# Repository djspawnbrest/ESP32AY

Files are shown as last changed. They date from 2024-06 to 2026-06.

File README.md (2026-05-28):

# ZxPod - multiformat Turbo Sound player
ESP32 based AY Turbo Sound multiformat player

## Fast flash firmware avaliable on [Alex Spawn OTA web page](https://ota.alexspawn.ru)

## Starting with firmware version 3.41 - added support for external DAC's - read [External DAC](PCB/ExternalDAC)

## IMPORTANT:
Firmwares from version 3.4 supports only PCB revision C! But you can soldering upgrade revision A and B to C:

Cut JP1 jumper on revisions A and B first!

### From rev.A to B and C:
You need to cut the input track on the resistor R33(see Pic.2) and solder the wire from the ESP32 (see Pic.1) to the cut contact of the resistor. See the images below.
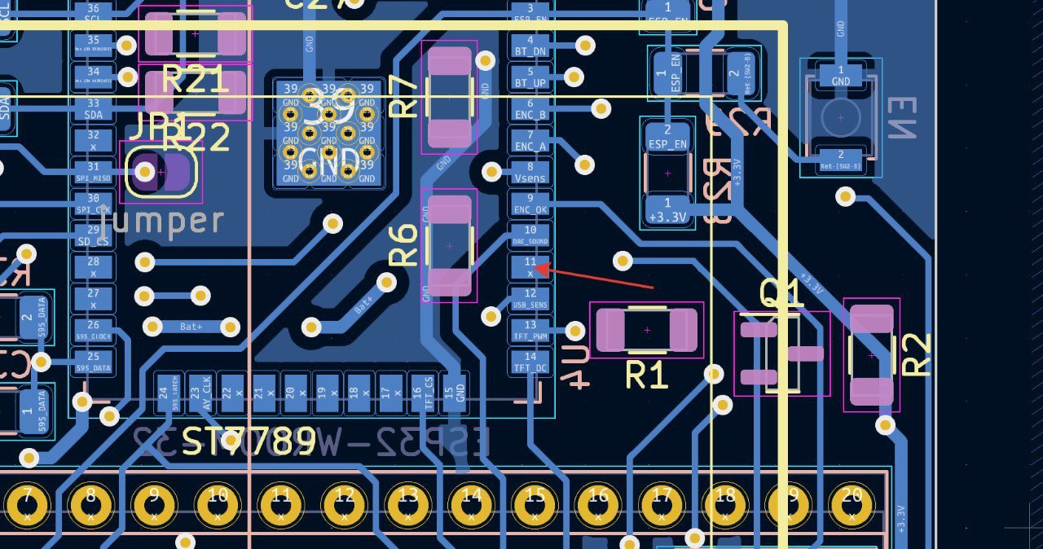
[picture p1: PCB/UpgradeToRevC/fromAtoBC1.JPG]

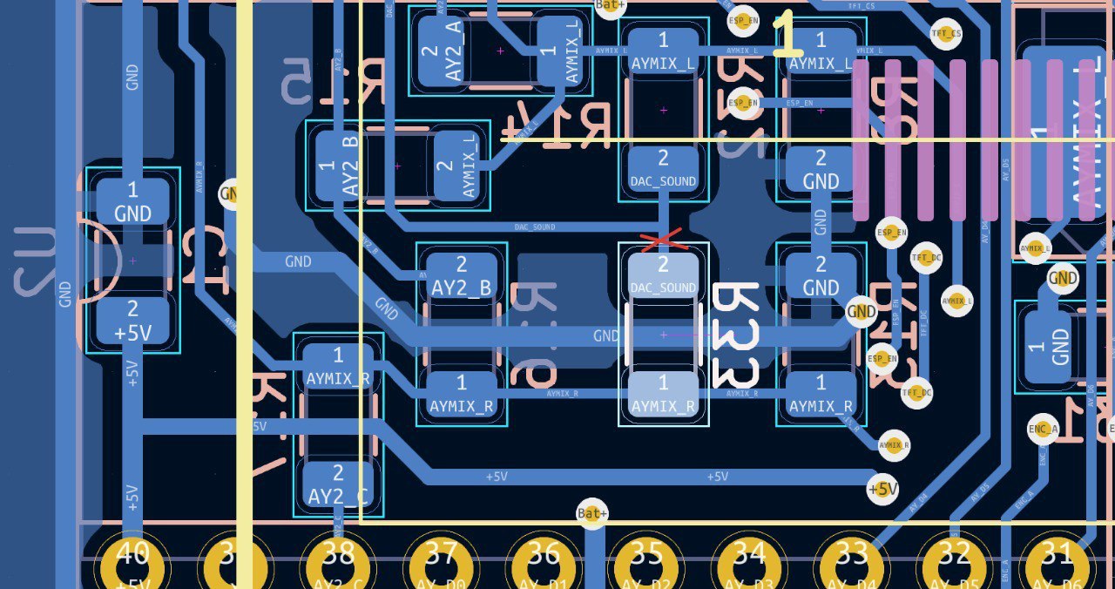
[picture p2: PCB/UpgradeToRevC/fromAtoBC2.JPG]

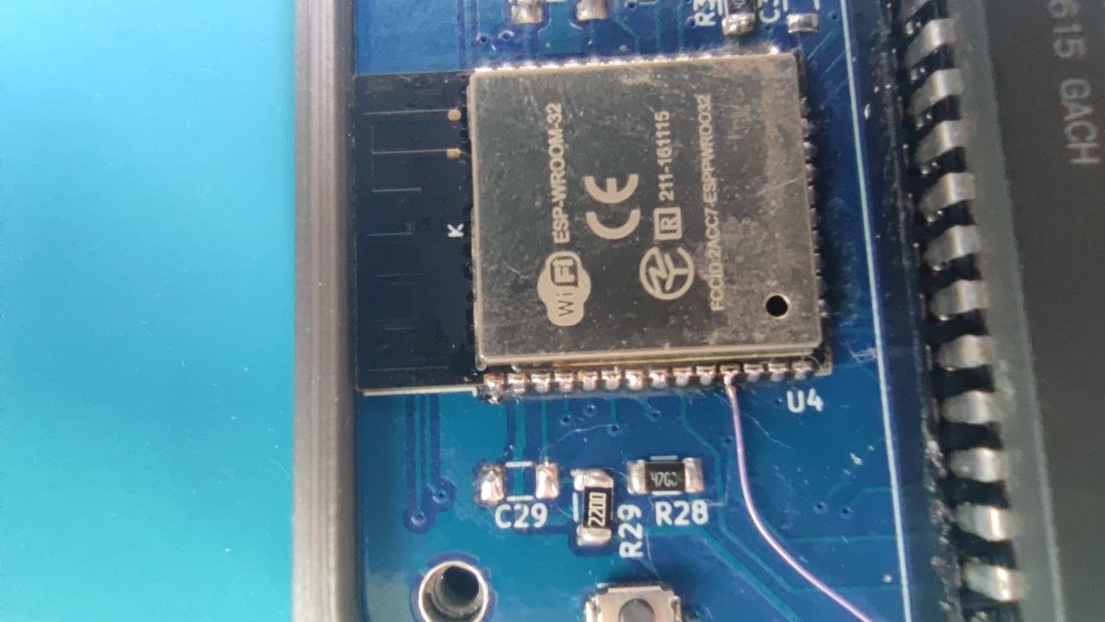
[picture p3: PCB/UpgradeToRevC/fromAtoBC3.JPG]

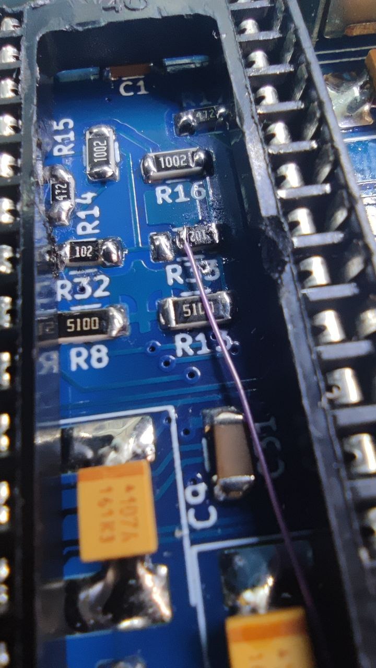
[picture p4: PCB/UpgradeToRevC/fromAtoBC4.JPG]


### From rev. A and B to C:
You need to cut the tracks as shown in Figure 5 (red cut lines), then carefully strip the tracks from the solder mask and solder the wires (green lines) to the ESP32.
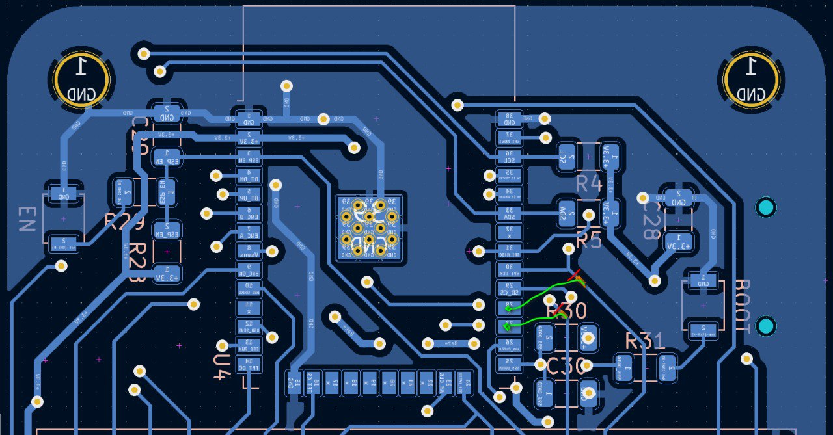
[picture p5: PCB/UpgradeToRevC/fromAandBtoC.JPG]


## Features
### Supported formats:
- .ayl - [Ay_Emul](https://bulba.untergrund.net/emulator_e.htm) by Sergey Bulba own playlist format
- .pt1 - Pro Tracker v1 file format
- .pt2 - Pro Tracker v2 file format
- .pt3 - Pro Tracker v3 (include Turbo Sound on two AY chips) file format
- .stc - Sound Tracker file format
- .stp - Sound Tracker Pro file format
- .asc - Sound Master file format 
- .psc - Pro Sound Creator file format
- .sqt - SQ Tracker file format
- .ay  - AY file format
- .psg - Programmable Sound Generator file format
- .rsf - Registers Stream Flow file format
- .yrg - [Custom AVR-AY format](https://www.avray.ru/ru/avr-ay-player/)
- .mod - Amiga MOD tracker format designed for creating, storing and playing music on an Amiga PC
- .s3m - (Scream Tracker 3 Module) is a module file format, based on the original MOD format used on the Amiga computer.
- .xm  - The XM file format, also known as Extended Module, is a digital audio file type for music created in the FastTracker 2 software (rev.D and above only).
- .tap - A file format for emulating ZX Spectrum magnetic tape images, which stores data from standard Sinclair BASIC procedures for working with a cassette.
- .tzx - A file format used to store programs and games for the ZX Spectrum computer as audio data from magnetic tape.
- .mp3 - MP3 (MPEG-1 Audio Layer 3) is a widely used digital audio format that uses a lossy compression method to significantly reduce file size while maintaining near-CD quality audio.
- .wav - is an audio file format for storing uncompressed audio data, developed by Microsoft and IBM. It is known for high-quality audio that retains all original data, but results in large file sizes, making it popular for professional audio recording and editing. The format stores audio data in chunks and commonly uses linear pulse-code modulation (LPCM) for encoding.
- UART mode (available in player settings menu as Player source)
- SD forwarding via USB as Mass Storage device (rev.D and above only) (press left button("-") and turn ON player)

### Controls
- Before player turning on - hold left button and turn on player to enter root config (needed for change encoder type). Encoder types:
    1. STEP 4L - active low (pull-up to VCC). Full cycle (4 phases) per click.
    2. STEP 4H - active high (pull-up to GND). Full cycle (4 phases) per click
    3. STEP 2 - half cycle (2 phases) per click (Set by default)
    4. STEP 1 - quarter cycle (1 phase) per click, and non-latching encoders
- Before player turning on - hold right button and turn on player to reset config to default.
- Before player turning on - hold encoder button and turn on player to reset last playing track (if player freezes or reboot on this file).
- Encoder Hold - change mode player/file browser
- Encoder Click - in player mode - play/pause; in file browser mode select track/playlist/directory; select - in config mode
- Encoder Double click - in player mode - open settings
- Encoder Push and turn right - fast forward (for ay format change next subsong, for tape formats - change next block)
- Encoder Push and turn left - slow down (for ay format change previous subsong, for tape formats - change previous block)
- Left button click/hold - volume - (in player mode); cancel - in config mode
- Right button click/hold - volume + (in player mode)
- Left button double click - change AY clock (in player mode) for PSG formats or change stereo panning for formats over DAC (mod,s3m etc.)
- Right button double click - change play mode: all/shuffle/once (in player mode)
- Right button hold and encoder click - remove file (only files, only in file browser).
- Right button click - change file sorting in file browser. (only in file browser).

### Playing modes:
- Playing all tracks (in folder/playlist)
- Playing random track (in folder/playlist)
- Playing once track (loop)

### Supports fully realtime file browser

### Supports realtime AY layers change:
- ABC
- ACB
- BAC
- BCA
- CAB
- CBA

### Supports realtime AY clock change:
- ZX SPECTRUM - 1773400 Hz
- PENTAGON - 1750000 Hz
- MSX - 1789772 Hz
- CPC - 1000000 Hz
- ATARI ST - 2000000 Hz

### Built-in battery

### Built-in charger and indication on LED and TFT

### Built-in headphones stereo amplifier controlled by I2C bus

## Demo video with digital sound record:

Watch the video (https://youtu.be/-dr-m1xszBs)

### UPD 22.10.2024
- Add new feature: "UART mode" with AVR-AY player through UART.

### UPD 04.03.2025
- Add new formats: .mod and .s3m tracker module formats
- Change PCB to revision C

### UPD 18.06.2025
- Change PCB to revision D (ESP32 chip change to ESP32-S3 (N16R8) chip)

### UPD 16.07.2025
- SD forwarding via USB as Mass Storage device (rev.D and above only)

### UPD 12.09.2025
- Add .xm file format (rev.D and above only). Change Firmware version to 3.5

### UPD 15.10.2025
- Add .tap, .tzx formats to play and loads programms on ZX-Spectrum.

### UPD 08.10.2025
- Add .mp3, .wav formats.

### UPD 10.10.2025
- Add file sorting in file broser on right button click!

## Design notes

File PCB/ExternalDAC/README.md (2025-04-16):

# ZxPod Player withexternal DAC use
## Revisions A,B and C.

You may use external DAC like PCM5102A module.

### First prepare PCM5102A module

1. Solder SCK jumper on top side.
2. Solder jumpers on bottom side: 1 - LOW, 2 - LOW, 3 - HIGH, 4 - LOW

### Prepare ZxPod
1. Remove R18, R19, R32, R33 (on revisions A,B and C).
2. Connect BCK DAC pin to GPIO25, DIN DAC pin to GPIO26, LRCK DAC pin to GPIO27 (see Fig.1)
3. Connect VIN DAC pin to 5V on player and GND DAC pin to GND on player (You may use 3,3V linear regulator pins on player PCB, see Fig.2)
4. Connect LROUT DAC pin to LOUT pad R32 (see Fig.2), ROUT DAC pin ROUT pad R33 (see Fig.2)
5. Fix the module, for example, with double-sided tape to the ESP32 module as shown in Fig.3

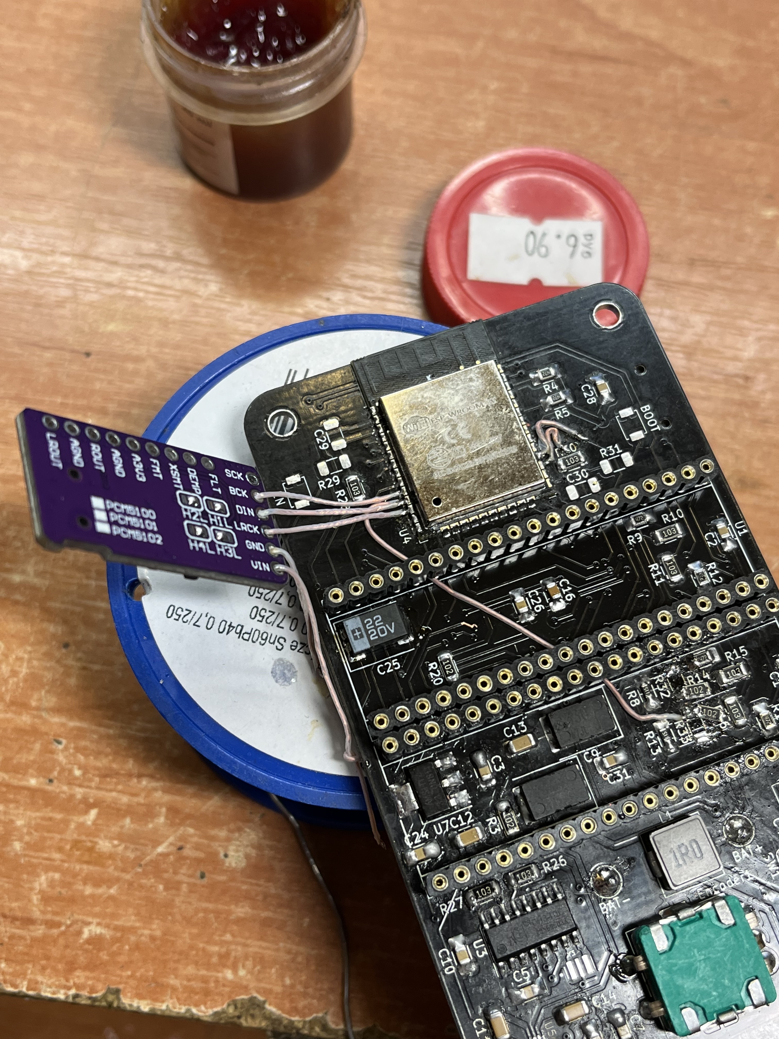
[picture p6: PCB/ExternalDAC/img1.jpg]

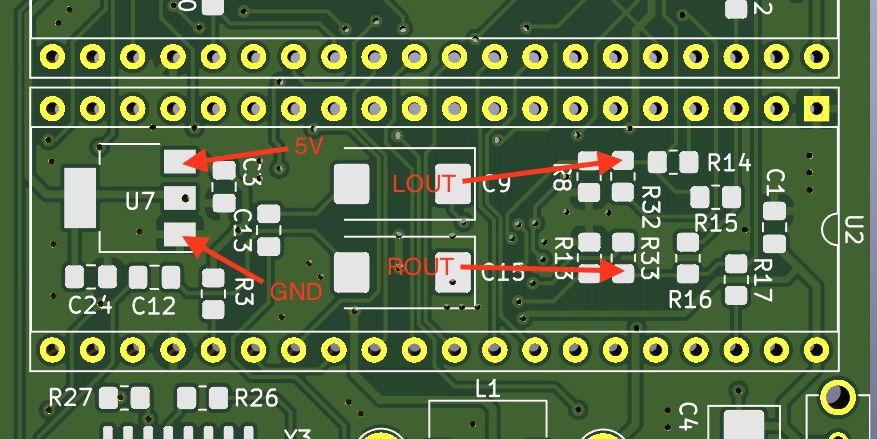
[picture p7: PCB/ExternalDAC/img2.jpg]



External DAC support starting from firmware version 3.41.
Also fast firmware flash avaliable on [Alex Spawn OTA web page](https://ota.alexspawn.ru)

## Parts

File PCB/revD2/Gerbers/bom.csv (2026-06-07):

Designator | Footprint | Quantity | Value | LCSC Part #
C1 | CP_EIA-7343-31_Kemet-D-uni | 1 | 100uf
C10, C24, C27, C37, C38, C39, C40, C41, C42, C9 | 0805 | 10 | 10uf
C11, C14, C17 | 1206 | 3 | 22uf
C12, C13, C15, C16, C18, C19, C2, C20, C21, C22, C25, C29, C3, C34, C35, C36, C4, C5, C6, C7 | 0805 | 20 | 100n
C23, C43, C44 | 0805 | 3 | 2.2uf
C26, C28 | 0805 | 2 | 2.2nf
C30, C31, C32, C33 | 0805 | 4 | 470n
C8 | CP_EIA-7343-31_Kemet-D-uni | 1 | 47uf
D1 | 0805 | 1 | OK
D2 | 0805 | 1 | CHRG
D3 | D_SOD-323F | 1 | PMEG4010CEJ
D4 | D_SMA | 1 | SS14
D5 | 0805 | 1 | PWR
ENCODER1 | RotaryEncoder_Alps_EC11E-Switch_Vertical_H20mm | 1 | RotaryEncoder_Switch
J1 | USB_C_Receptacle_G-Switch_GT-USB-7010ASV | 1 | USB_C_Receptacle_USB2.0_14P
J2 | JST_PH_S2B-PH-K_1x02_P2.00mm_Horizontal | 1 | Battery
J3 | TFP09212B | 1 | SD Card
J4 | AUDIO_JACK_3.5MM_SMD_TRRS_rounded_mixed | 1 | MiniJack
L1 | L_Bourns_SRN8040TA | 1 | 22uH
Q1 | SOT-23 | 1 | IRLML6402
Q2 | SOT-23 | 1 | BC807
R1, R11, R13, R18, R2, R25, R26, R32, R39, R40, R41, R42, R6, R7, R8, R9 | 0805 | 16 | 10K
R10, R22, R23, R24, R29, R45, R46, R47, R48, R49, R50 | 0805 | 11 | 1k
R12 | 0805 | 1 | 8,2К*
R14 | 0805 | 1 | 1M
R15 | 0805 | 1 | 100K
R16 | 0805 | 1 | 2k*
R17, R19 | 0805 | 2 | 220
R20 | 0805 | 1 | 47k
R21 | 0805 | 1 | 6.2k
R27, R28, R30, R31 | 0805 | 4 | 470
R3, R4 | 0805 | 2 | 5K1
R33, R34, R35, R36, R37, R38 | 0805 | 6 | 4.7K
R43, R44 | 0805 | 2 | 1.5K
R5 | 0805 | 1 | 2R
R51, R52 | 0805 | 2 | 15K
S1 | SW_Push_1P1T_NO_6x6mm_H9.5mm | 1 | DOWN
S2 | SW_Push_1P1T_NO_6x6mm_H9.5mm | 1 | UP
S3 | SW_EG1213 | 1 | EG1213
SW1 | SW_SPST_PTS810_handsoldering | 1 | BOOT
SW2 | SW_SPST_PTS810_handsoldering | 1 | EN
TFT1 | ST7789 | 1 | ST7789
U1 | SOT-223-3_TabPin2 | 1 | AMS1117-3.3
U10 | TSSOP-20_4.4x6.5mm_P0.65mm | 1 | PCM5102A
U11 | ESP32-S3-WROOM-1 | 1 | ESP32-S3-WROOM-1
U12 | QFN50P400X400X80-21N | 1 | TPA6130A2RTJTG4 | TPA6130A2RTJTG4
U2, U3 | SO-16_3.9x9.9mm_P1.27mm | 2 | 74HC595
U4 | SOIC-8-1EP_3.9x4.9mm_P1.27mm_EP2.41x3.3mm_ThermalVias | 1 | TP4056
U5, U7 | DIP-40_W15.24mm_Socket | 2 | AY-3-8910
U6 | SOIC-8_3.9x4.9mm_P1.27mm | 1 | DS3231MZ
U8 | SOT-23-6_Handsoldering | 1 | SDB628
U9 | SOIC-8_3.9x4.9mm_P1.27mm | 1 | 24С32

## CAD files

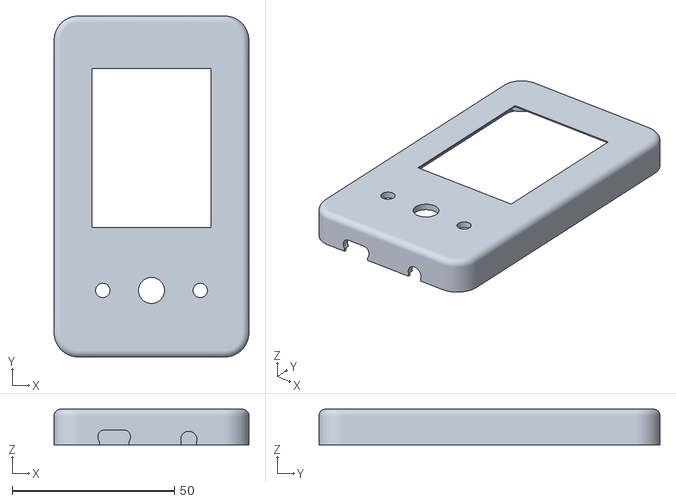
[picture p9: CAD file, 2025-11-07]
Case/TopRevABCD.stl
60.0 x 105.0 x 11.0

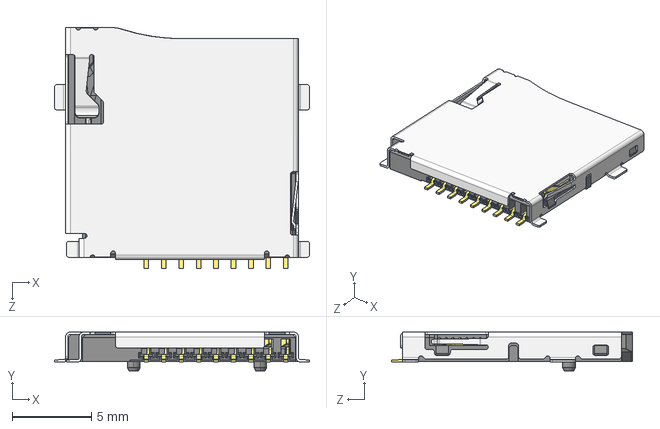
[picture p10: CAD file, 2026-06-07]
PCB/revD2/KiCad/3d/TFP09-2-12B.stp
16.1 x 2.45 x 15.2 mm

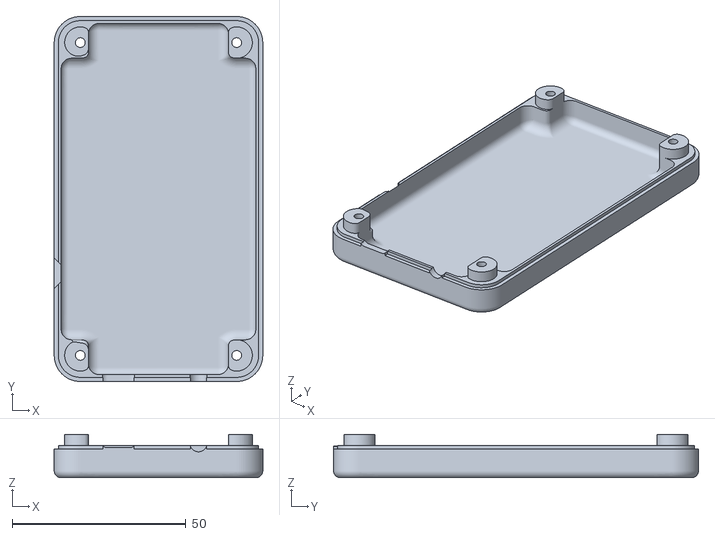
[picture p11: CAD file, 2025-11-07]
Case/BottomRevABCD.stl
60.0 x 105.0 x 12.5

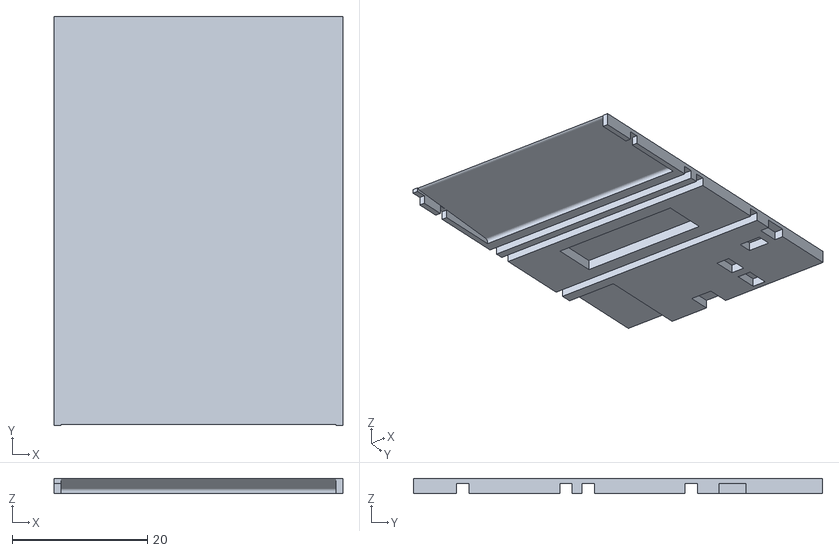
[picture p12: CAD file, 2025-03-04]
Case/LCDspacerRevABCD.stl
42.7 x 60.4 x 2.21

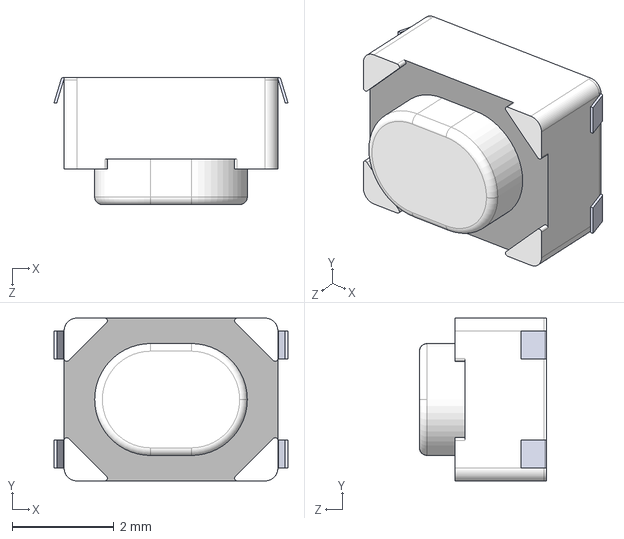
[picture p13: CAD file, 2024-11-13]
PCB/revD2/KiCad/3d/PTS810 Series SJS 250.STEP
4.60 x 3.20 x 2.50 mm

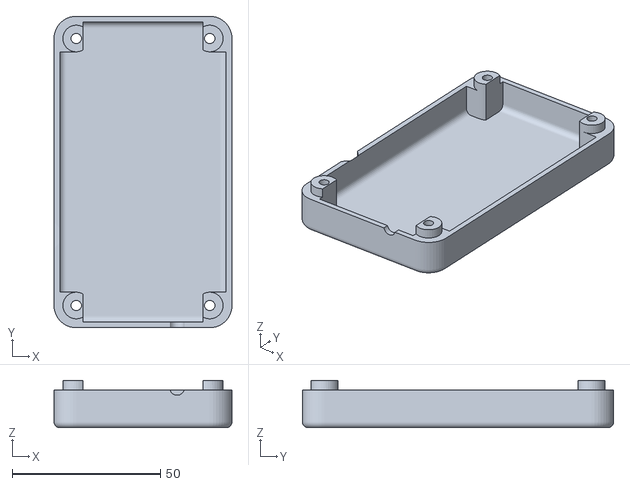
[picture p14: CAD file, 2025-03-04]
Case/ExtendedBottomMicroUsbRevA.stl
60.0 x 105.0 x 16.0

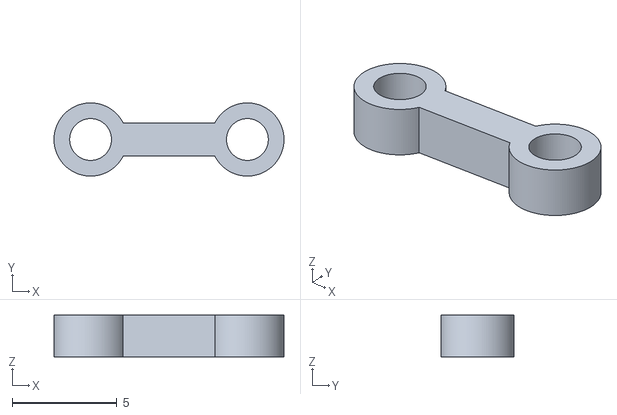
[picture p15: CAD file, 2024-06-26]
PCB/revD2/KiCad/3d/heliPerem.stl
11.0 x 3.50 x 2.00

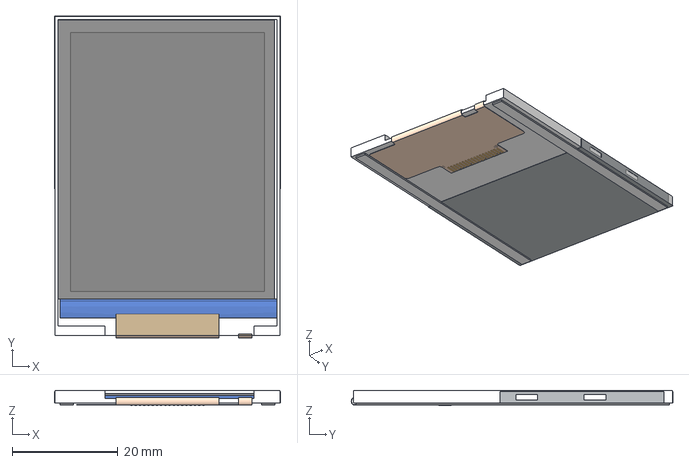
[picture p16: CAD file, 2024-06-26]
PCB/revD2/KiCad/3d/2.4 TFT Module.step
42.7 x 60.8 x 2.74 mm

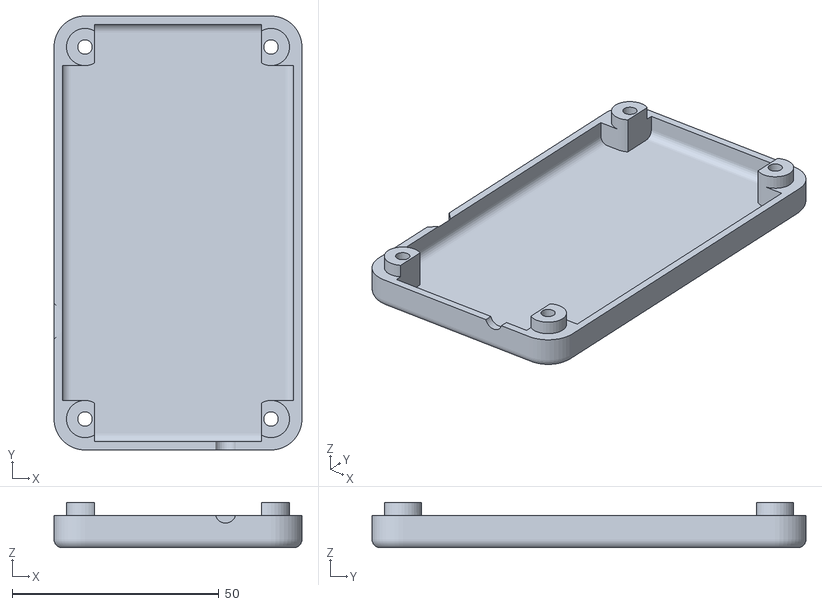
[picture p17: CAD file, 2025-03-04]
Case/BottomMicroUsbRevA.stl
60.0 x 105.0 x 11.0

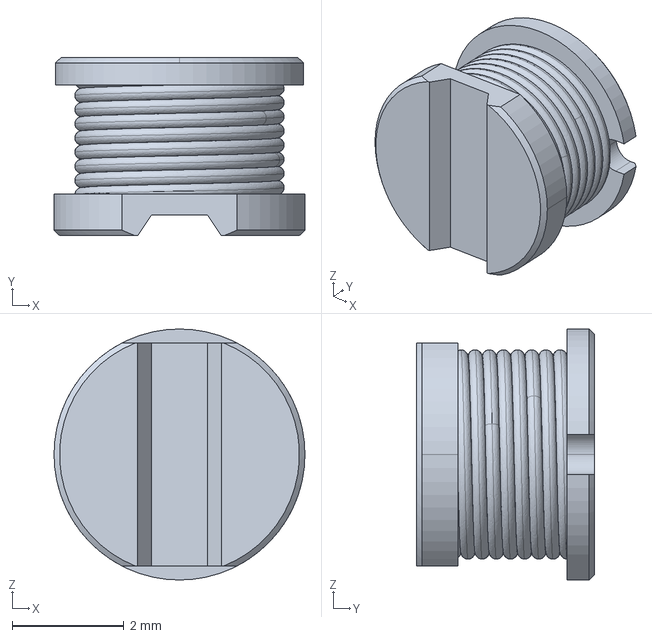
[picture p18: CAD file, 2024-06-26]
PCB/revD2/KiCad/3d/SDR0403-221KL.step
4.50 x 3.20 x 4.50 mm

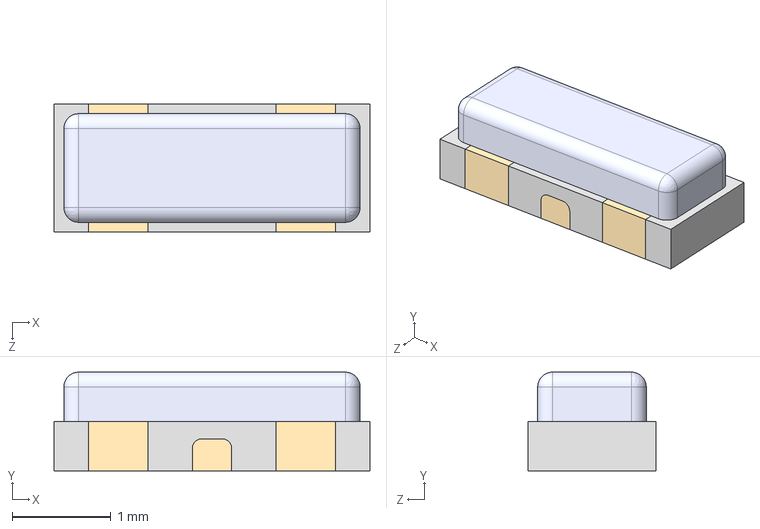
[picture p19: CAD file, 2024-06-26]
PCB/revD2/KiCad/3d/CSTCE16M0V53-R0.step
3.20 x 1.00 x 1.30 mm

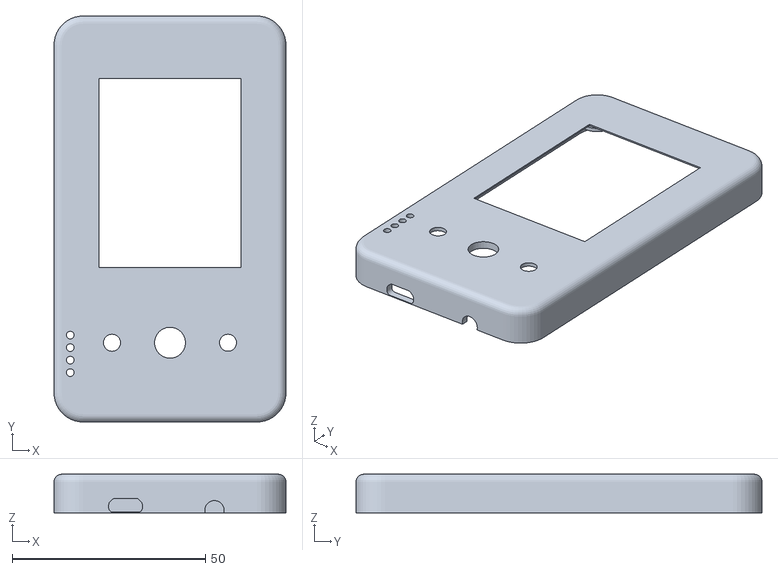
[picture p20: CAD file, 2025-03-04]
Case/TopMicroUsbRevA.stl
60.0 x 105.0 x 10.00

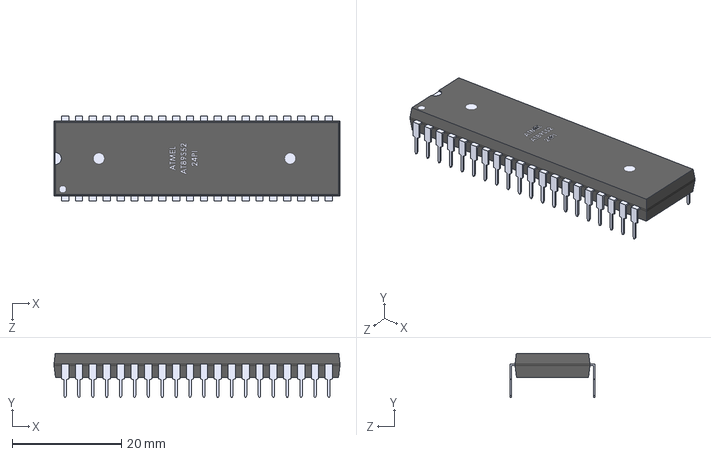
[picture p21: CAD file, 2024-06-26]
PCB/revD2/KiCad/3d/AYDIP40_MODEL.STEP
52.3 x 8.13 x 15.6 mm
AT89S52_PIN21to40 x 40
AT89S52_body

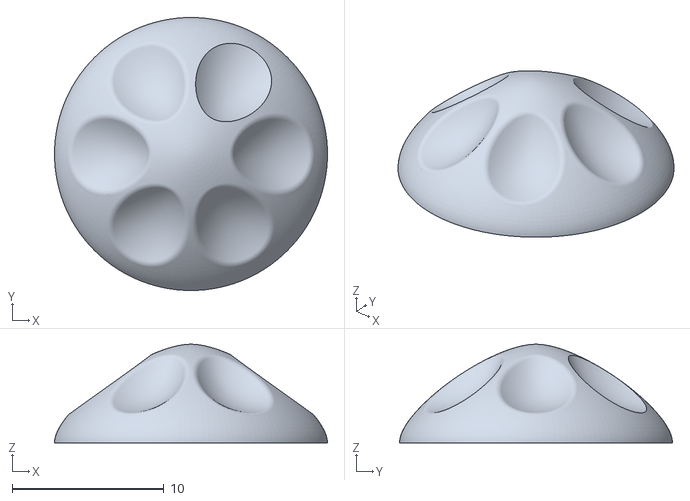
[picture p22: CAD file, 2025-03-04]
Case/EncoderKnob.stl
18.0 x 18.0 x 6.50

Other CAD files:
Case/ExtendedBottomTypeCRevBC.stl
Case/BottomTypeCRevBC.stl
PCB/revD2/KiCad/3d/ZX62D-B-5P8.step
Case/OldCases/BottomTypeCRevBC.stl
Case/OldCases/ExtendedBottomTypeCRevBC.stl
Case/OldCases/TopTypeCRevBC.stl
Case/TopTypeCRevBC.stl
PCB/revD2/KiCad/3d/35RAPC2BHN2.step
PCB/revD2/KiCad/3d/ArduinoMega_STEP_AP203.STEP
PCB/revD2/KiCad/3d/EC11-THT-15F.step
PCB/revD2/KiCad/3d/EC11-THT-15_rotated.step
PCB/revD2/KiCad/3d/EG1213.step
PCB/revD2/KiCad/3d/FSM8J.STEP
PCB/revD2/KiCad/3d/GMT177-01.iges
PCB/revD2/KiCad/3d/ME2108A33P.step
PCB/revD2/KiCad/3d/SS14.step
PCB/revD2/KiCad/3d/SSD1306_OLED_Display(128x64).step
PCB/revD2/KiCad/3d/TP4056.step
PCB/revD2/KiCad/3d/TPA6130A2RTJTG4.step
PCB/revD2/KiCad/3d/Tactal Switch -Thru (6mmx 6mmx9.0mm).stp
PCB/revD2/KiCad/3d/audio_3.5mm_trrs.STEP
PCB/revD2/KiCad/3d/tft1.8.step

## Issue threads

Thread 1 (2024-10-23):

Another display

kpbicka, 2024-10-23:
Добрый день. Возможно ли пересобрать под использование дисплеев на контроллере ILI9341 ?

djspawnbrest, 2024-10-24:
Да, библиотека поддерживает этот контроллер

kpbicka, 2024-10-24:
> > Добрый день. Возможно ли пересобрать под использование дисплеев на контроллере ILI9341 ?
>
> Да, библиотека поддерживает этот контроллер, надо только в библиотеке его выбрать и прописать настройки. Соответственно пины проверить на совместимость.

А ещё расскажите, пожалуйста, как оно работает по UART (ну или где это описано - не нашёл)

kpbicka, 2024-10-24:
И в веб-прошивальщике неплохо бы сделать выбор скорости, а то не всегда получается на той, что по умолчанию (которая не отображается) :)

djspawnbrest, 2024-10-24:
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

Заходим в настройки (двойной клик энкодера из плеера), там верхний пункт меню "Player Source" - переключает источник проигрывания SD/UART. Качаем плеер AVR-AY Player, устанвливаем, запускаем его, снимаем галочку "USE SOUND CARD", выбираем ком порт подключенного плеера - Open. Запускаем треки из плейлиста плеера.....

djspawnbrest, 2024-10-24:
> И в веб-прошивальщике неплохо бы сделать выбор скорости, а то не всегда получается на той, что по умолчанию (которая не отображается) :)

Такой реализации у разработчика пока нет.

djspawnbrest, 2024-10-24:
> >
>
> а почему у вас в User_Setup.h #define ILI9341_DRIVER но используется вроде ST7789 ?

Потому что это всего лишь название файла с его id, а если посмотреть его внутри то там вообще прописан [#define ST7789_DRIVER](https://github.com/djspawnbrest/ESP32AY/blob/main/lib/TFT_eSPI/User_Setups/Setup42_ILI9341_ESP32.h#L7). Просто по набору настроек больше подходил мне, вот его я и переписал.

mszulen, 2024-12-18:
And what, exactly display did you use? Any chance for a link to the seller?

djspawnbrest, 2024-12-18:
> And what, exactly display did you use? Any chance for a link to the seller?

For example use this: https://aliexpress.ru/item/1005005824438283.html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
or
https://aliexpress.ru/item/1005005287329824.html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

It doesn't matter with touch or without, it is not used.

mszulen, 2024-12-18:
Perfect! Thank you! :)

Closed 2025-02-10.

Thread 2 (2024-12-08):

ESP32 version

mszulen, 2024-12-08:
Does it matter which version of ESP32 WROOM 32 is used? I mean 32, 32D, 32E ?

djspawnbrest, 2024-12-08:
I used 32 version

mszulen, 2024-12-09:
Thanks! According to specs, the "D" version doesn't seem to be different on the functional level. Do you think it will also work? This is what I have.

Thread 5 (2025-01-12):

Initial run issues (was: Blinking led and no boot)

mszulen, 2025-01-12:
Firmware has been flashed suscesfully, but it does not boot.
Does it require the battery too or it can run on usb only?
I'm getting the "25%" led blinking and the LCD just blinks once (or sometimes not) after I turn it on.
Any suggested areas to check?

djspawnbrest, 2025-01-12:
It is better to connect the battery, the charging controller does not work without it.

mszulen, 2025-01-12:
Thanks!
Ok, I've had to:
1. flash the combined firmware (separate components did not work for some reason)
2. add the battery

It did boot (I can add AY chips and buttons now).

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

However, there's a weird behaviour:

Looks like It turns on ONLY every second flip of the switch.

This is the sequence I observe

1. flip switch to ON - nothing happens (no LEDs, no LCD)
2. flip to OFF
3. flip to ON again - LEDs come on and it boots
4. flip to OFF
5. go to step 1

Is this somehow to avoid?

mszulen, 2025-01-12:
And one step further.
With and without encoder, it behaves like the encoder was pushed/turned all the time (see the video).
I've tried beta and merged firmware - no change.

pins 6, 7, 9 of ESP are on ab. 3.2V
Rotating or shorting of the encoder pins does drop the voltage on those pins, so looks like resistors and capacitors there are ok.

https://drive.google.com/file/d/1z1_PquUsFGeYMXxUE6-IOWNntH5dRp3-/view?usp=sharing

djspawnbrest, 2025-01-12:
ym format is not supported, see readme) you need to write on your sd card only supported formats.

djspawnbrest, 2025-01-12:
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

See your connections on PCB

andykarpov, 2025-01-12:
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

I can confirm exactly the same issue like on the video with that play/pause loop for every 0.5-1 seconds after flashing the firmware and first run. Then somehow after some clicks on the encoder button to enter the setup menu, choosing the UART mode - it was gone. I think this is a software bug somewhere that needs to be investigated and fixed.

mszulen, 2025-01-12:
> ym format is not supported, see readme) you need to write on your sd card only supported formats.

Right. I've selected correct files later but behaviour was the same.
Somehow, After trying to click, rotate encoder, I've got to the file list and the encoder was working correctly. I could select/play the files (but not skip to next/previous track with hold/turn). I've replicated the issue by selecting "reset to default" in the setting menu.
The encoder stopped working again.
Is there some parameter that causes this?

Btw, wouldn't it work if the track skipping was done by just rotation of the encoder. Seem like most of the times mine doesn't register press and turn and just goes to the file list like with long-press.

mszulen, 2025-01-12:
> I can confirm exactly the same issue like on the video with that play/pause loop for every 0.5-1 seconds after flashing the firmware and first run. Then somehow after some clicks on the encoder button to enter the setup menu, choosing the UART mode - it was gone. I think this is a software bug somewhere that needs to be investigated and fixed.

exactly same thing in my case. But it was gone again after reset to defaults.

andykarpov, 2025-01-12:
I think it could be related to the LittleFS storage uses on flash to store config files.
Maybe LittleFS requires a forced format before usage on first start?
You can provide a first argument to ```true``` while calling the ```LittleFS.begin()```

andykarpov, 2025-01-12:
Well, another finding is the F_CPU/256 is not equal to 312500. The current F_CPU is 160000000, so to get 312500 we have to divide F_CPU by 512... After changing that parameter to F_CPU/512 a strange noise from DAC has gone! And the initial boot also seems works fine.

mszulen, 2025-01-12:
It's amazing, how one finding leads to another :)
Thank you, guys for working on this.
What about the track skip? Is it viable/possible to skip tracks by turning the encoder only instead of press-turn?

djspawnbrest, 2025-01-12:
> It's amazing, how one finding leads to another :) Thank you, guys for working on this. What about the track skip? Is it viable/possible to skip tracks by turning the encoder only instead of press-turn?

it is intended that simply turning switches the next/previous track, but pressing and turning speeds up and slows down the track (in player mode, not file browser).

andykarpov, 2025-01-12:
> > Well, another finding is the F_CPU/256 is not equal to 312500. The current F_CPU is 160000000, so to get 312500 we have to divide F_CPU by 512... After changing that parameter to F_CPU/512 a strange noise from DAC has gone! And the initial boot also seems works fine.
>
> Thank you for feedback, I forgot about this when changed CPU speed, I fix this moment soon.

Well, my finding with the F_CPU fixes the DAC noise problem, but it's seems "reset to defaults" still produces that strange loop in player mode with bad encoder/buttons reaction. But definitely it's related to the DAC somehow, I guess.

andykarpov, 2025-01-12:
Steps to reproduce a case with stuck on play loop:
1. SD card should contain only one directory "music" with some pt3 files in it
2. No other files or directories on the SD card root
=> The ```player()``` function stucks at ```PlayerCTRL.isFinish``` state

djspawnbrest, 2025-01-13:
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

For correct work, you must place at least one supported music file in the root of the SD card.

andykarpov, 2025-01-13:
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

Ah, that explains a lot :) Thanks! I think you should put that in the README.

djspawnbrest, 2025-02-09:
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

Added a new feature: when using the card for the first time or any initial launch of an "unknown" SD - now the player searches for any supported file on the entire memory card, including subfolders. Now there is no need to put at least one supported file in the root of the SD card.

Closed 2025-02-10.

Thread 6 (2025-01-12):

SD SPI speed

andykarpov, 2025-01-12:
30MHz seems a bit too much for some older microSD cards.
I suggest to reduce the SD SPI speed to, say, 8 MHz.

djspawnbrest, 2025-02-09:
> 30MHz seems a bit too much for some older microSD cards. I suggest to reduce the SD SPI speed to, say, 8 MHz.

Fixed to 8MHz:)

Closed 2025-02-10.

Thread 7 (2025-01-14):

Skipping tracks with encoder is unreliable.

mszulen, 2025-01-14:
Tried 2 encoders already.
When turning the encoder to skip to next/previous track, most of the times it doesn't react.
When rotating very slowly, the success rate is a bit better but still, not every time.
Wouldn't it be more reliable to repurpose the buttons?
Currently they're used for a long press (volume) and double press (options).
A single press would be pretty convenient for the track skipping.

djspawnbrest, 2025-02-10:
> Tried 2 encoders already. When turning the encoder to skip to next/previous track, most of the times it doesn't react. When rotating very slowly, the success rate is a bit better but still, not every time. Wouldn't it be more reliable to repurpose the buttons? Currently they're used for a long press (volume) and double press (options). A single press would be pretty convenient for the track skipping.

Try to change Encoder type in keypad.h in 14 row: enc.setEncType(EB_STEP2); where EB_STEP2 - encoder type. Possible variants:
EB_STEP4_LOW - active low (pull-up to VCC). Full cycle (4 phases) in one click. Set by default
EB_STEP4_HIGH - active high (pull-up to GND). Full cycle (4 phases) in one click
EB_STEP2 - half cycle (2 phases) in one click
EB_STEP1 - quarter cycle (1 phase) in one click, and non-latching encoders

andykarpov, 2025-04-08:
Could you please make possible to choose the encoder type on the setup screen somehow?
Maybe with the volume buttons instead of encoder rotations, because it is useless until setting up a correct encoder type.

Just ordered a batch of new encoders (12mm shaft length instead of 10mm) and now every tick generates 2 pulses instead of one. Annoying... so I guess my new encoders are EB_STEP4_LOW now instead of EB_STEP2 with half cycles... :(

andykarpov, 2025-04-14:
The master firmware already contains a feature by @djspawnbrest  to choose the encoder type.
To enter that initial setup, please **press and hold the left button while turning on the player**.

A new initial setup screen will appear and you'll be able to choose the encoder type.
Use the buttons and encoder button as well as hints on that screen to set up and save your encoder type.

Closed 2025-04-14.

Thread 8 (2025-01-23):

MOD firmware

andykarpov, 2025-01-23:
It seems the MOD file support is experimental, well, but the repository does not contain any code for it.
Could you please share the firmware with MOD files support ? Maybe in a separate branch would be great, if it is not ready yet for the master branch.

PS: Also waiting for fixes to the F_CPU divider ( #5 )

djspawnbrest, 2025-02-09:
> It seems the MOD file support is experimental, well, but the repository does not contain any code for it. Could you please share the firmware with MOD files support ? Maybe in a separate branch would be great, if it is not ready yet for the master branch.
>
> PS: Also waiting for fixes to the F_CPU divider ( [#5](https://github.com/djspawnbrest/ESP32AY/issues/5) )

A little later I will make a separate thread with this firmware (for now), but new features have also been added to it and the beta firmware with mod is available at https://ota.alexspawn.ru/

Closed 2025-04-14.

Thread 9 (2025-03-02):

Mp3 support

Magnetrix, 2025-03-02:
Any chance to add mp3 format to this super player??

djspawnbrest, 2025-03-04:
> Any chance to add mp3 format to this super player??

Yes, there are plans to add support, but first I will implement tracker formats;)

mszulen, 2025-03-05:
> > Any chance to add mp3 format to this super player??
>
> Yes, there are plans to add support, but first I will implement tracker formats;)

XM format would be really desirable here :)
BTW, what, exactly does the PCB change do in rev C? Pin 11 of ESP is DAC, correct?

andykarpov, 2025-04-08:
> BTW, what, exactly does the PCB change do in rev C? Pin 11 of ESP is DAC, correct?
>
> not only that, the screen also gets its own SPI

Please release firmware for both revisions (revC and pre-revC (A and B)).
I think not all users will be able to make changes to their PCBs.

djspawnbrest, 2025-04-09:
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

The thing is that the latest firmware added the s3m format, which is more voracious for reading data from the SD card and revision B will not cope with its playback, so there is no point in making the latest firmware release (v3.4 and higher) for revision B (the same applies to revision A), not to mention subsequent releases with new formats.

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

@mszulen As for the XM format (the same applies to the IT format) - I am working on it now, but I am afraid that the current hardware will not cope with it, the problem is that in these formats - samples have delta encoding and some tracks also have ADPCM encoding and on the fly esp32 does not have time to recode them (the SD card reading speed is not enough + there are not enough resources for mixing), so I am already thinking about replacing the standard ESP-WROOM-32 chip with an ESP32-WROVER-E which has 4 MB of PSRAM available on board - which, according to preliminary estimates, is enough to store recoded samples and read them directly from PSRAM.

@andykarpov I know you're not a bad programmer;) contact me in TG - @AlexSpawn - if you want to help with hardware and code;)

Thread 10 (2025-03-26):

Sometimes the player won't turn on (battery powered)

andykarpov, 2025-03-26:
The only thing helps is to plug the USB cable, then player turns on by the switch, then you can disconnect the cable.
That's a bit annoying thing and probably related to the SM5308 charger chip, maybe the load is too low for it to turn on.
Looking for a solution. May be some additional "load" resistor will help somewhere...

andykarpov, 2025-03-26:
Also, there were some mistakes in the schematic comparing to the reference datasheet: https://www.lcsc.com/datasheet/lcsc_datasheet_2301051530_HICHON-SM5308_C5345582.pdf

1. R23 should be 0.5 Ohm and R24 should be 0.1 Ohm
2. R24 should be connected a little bit different

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

andykarpov, 2025-03-26:
Here is some questions and answers about those "smart" chips: https://done.land/components/power/powersupplies/battery/chargers/charge-discharge/ip5306/

So, there are some workarounds to fix the issue:
1) we can add some resistor after the switch to increase the current load of the player.
2) we can play with some tricks described in the document regarding the push button

djspawnbrest, 2025-03-28:
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

Hi Andy! It is best to install the original IP5306 chip, it works most stably. As for the circuit diagram, it was taken from such a board (reverse engineering)

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

andykarpov, 2025-04-08:
Well, just arrived SM5308 from LCSC - works great! So, issue could be closed now :)
Message to all: please use a SM5308 or IP5306 as described in the BOM.

Closed 2025-04-08.

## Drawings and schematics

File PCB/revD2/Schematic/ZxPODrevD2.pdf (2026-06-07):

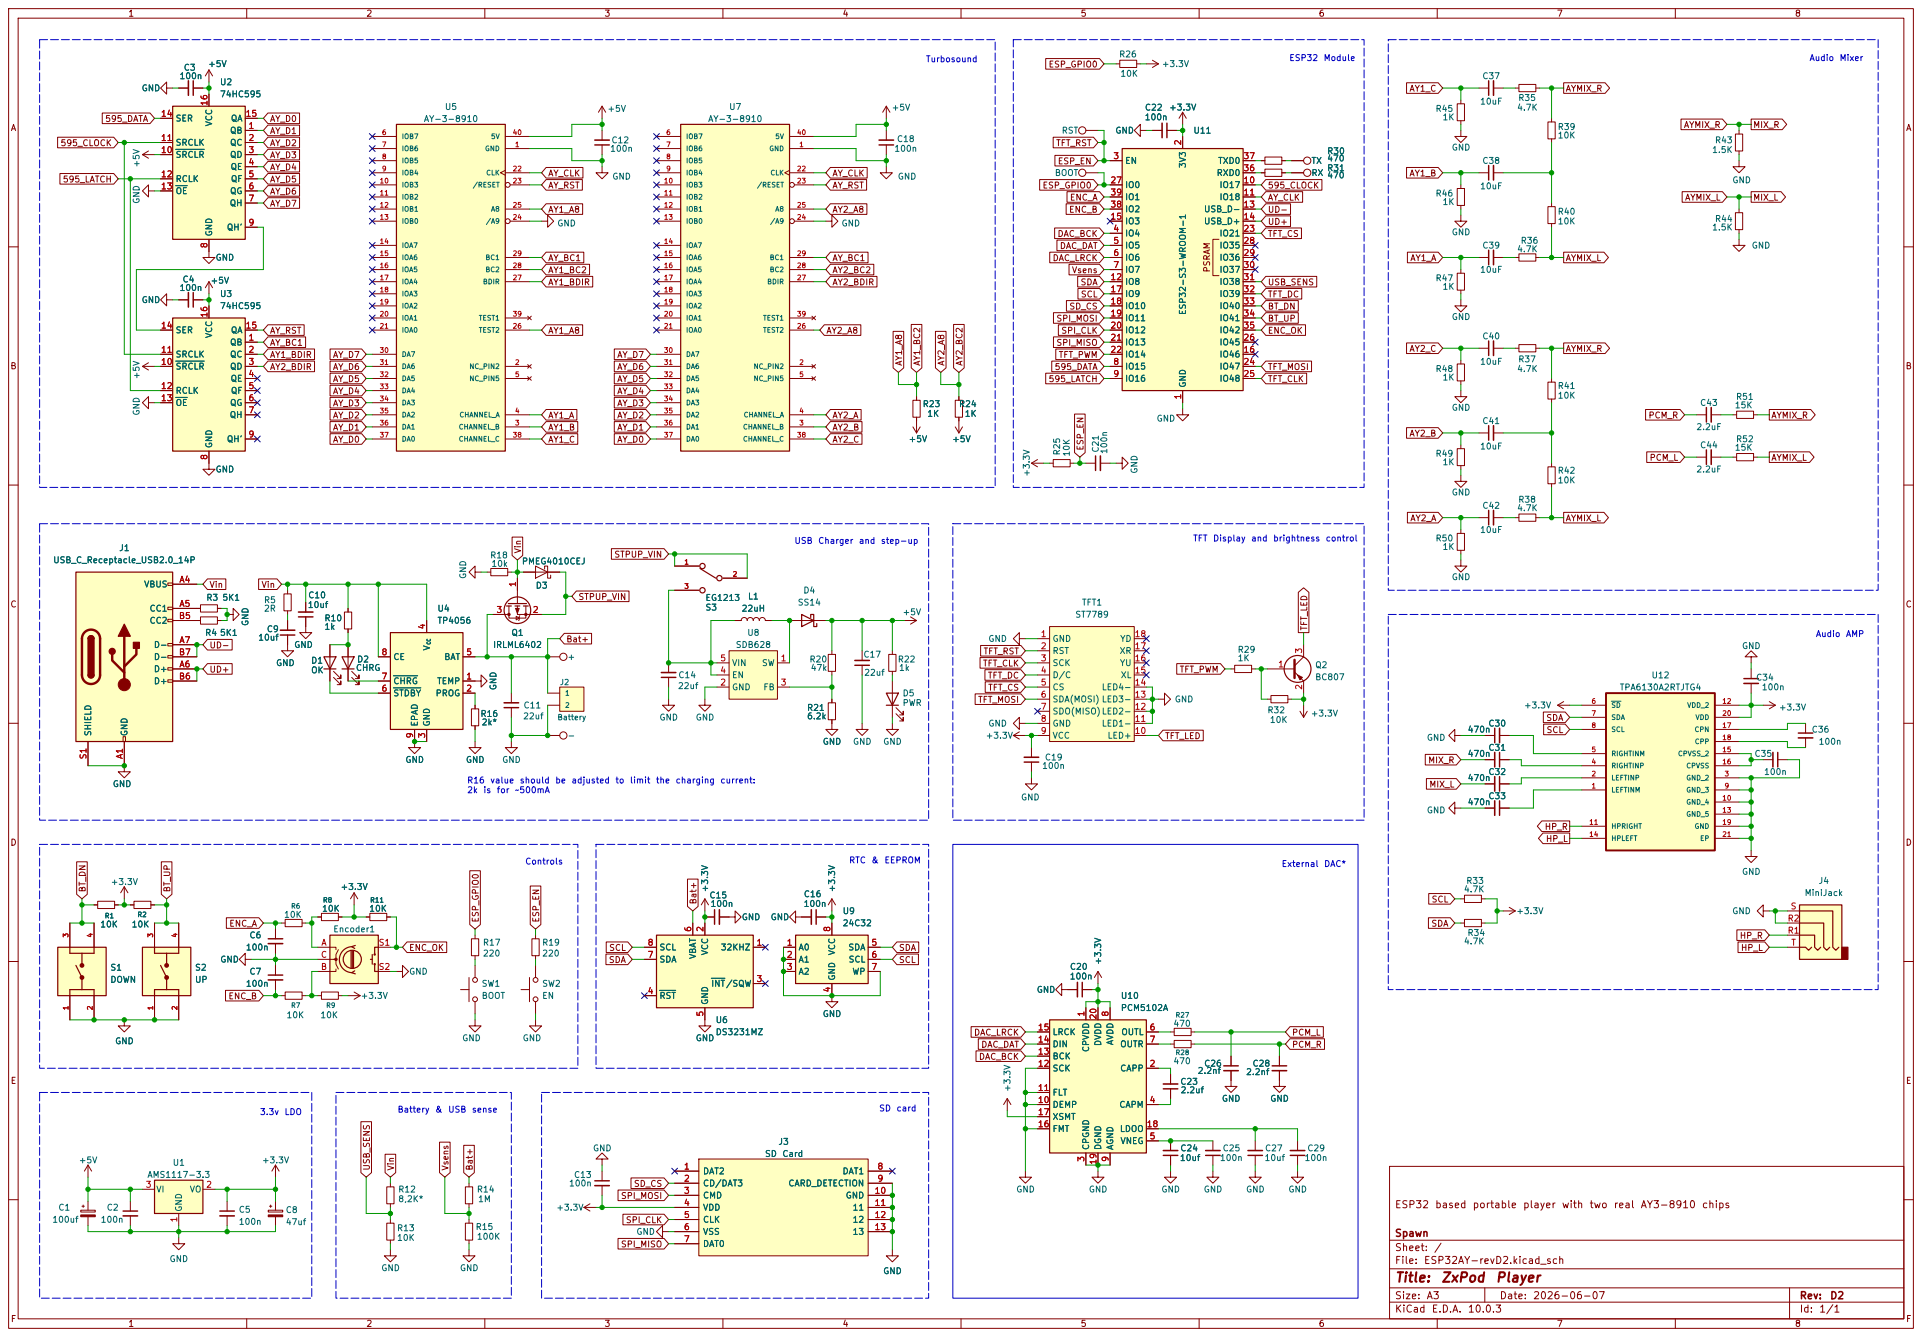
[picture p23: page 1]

GND GND GND GND +5V
74HC595 GND

SRCLR 10 SRCLK 11 RCLK 12 OE 13

USB Charger and step-up

External DAC* SD card

SCK 12 BCK 13 DIN 14 LRCK 15

ESP32 based portable player with two real AY3-8910 chips

Size: A3 | Rev: D2
KiCad E.D.A. 10.0.3 | Id: 1/1 | F Date: 2026-06-07

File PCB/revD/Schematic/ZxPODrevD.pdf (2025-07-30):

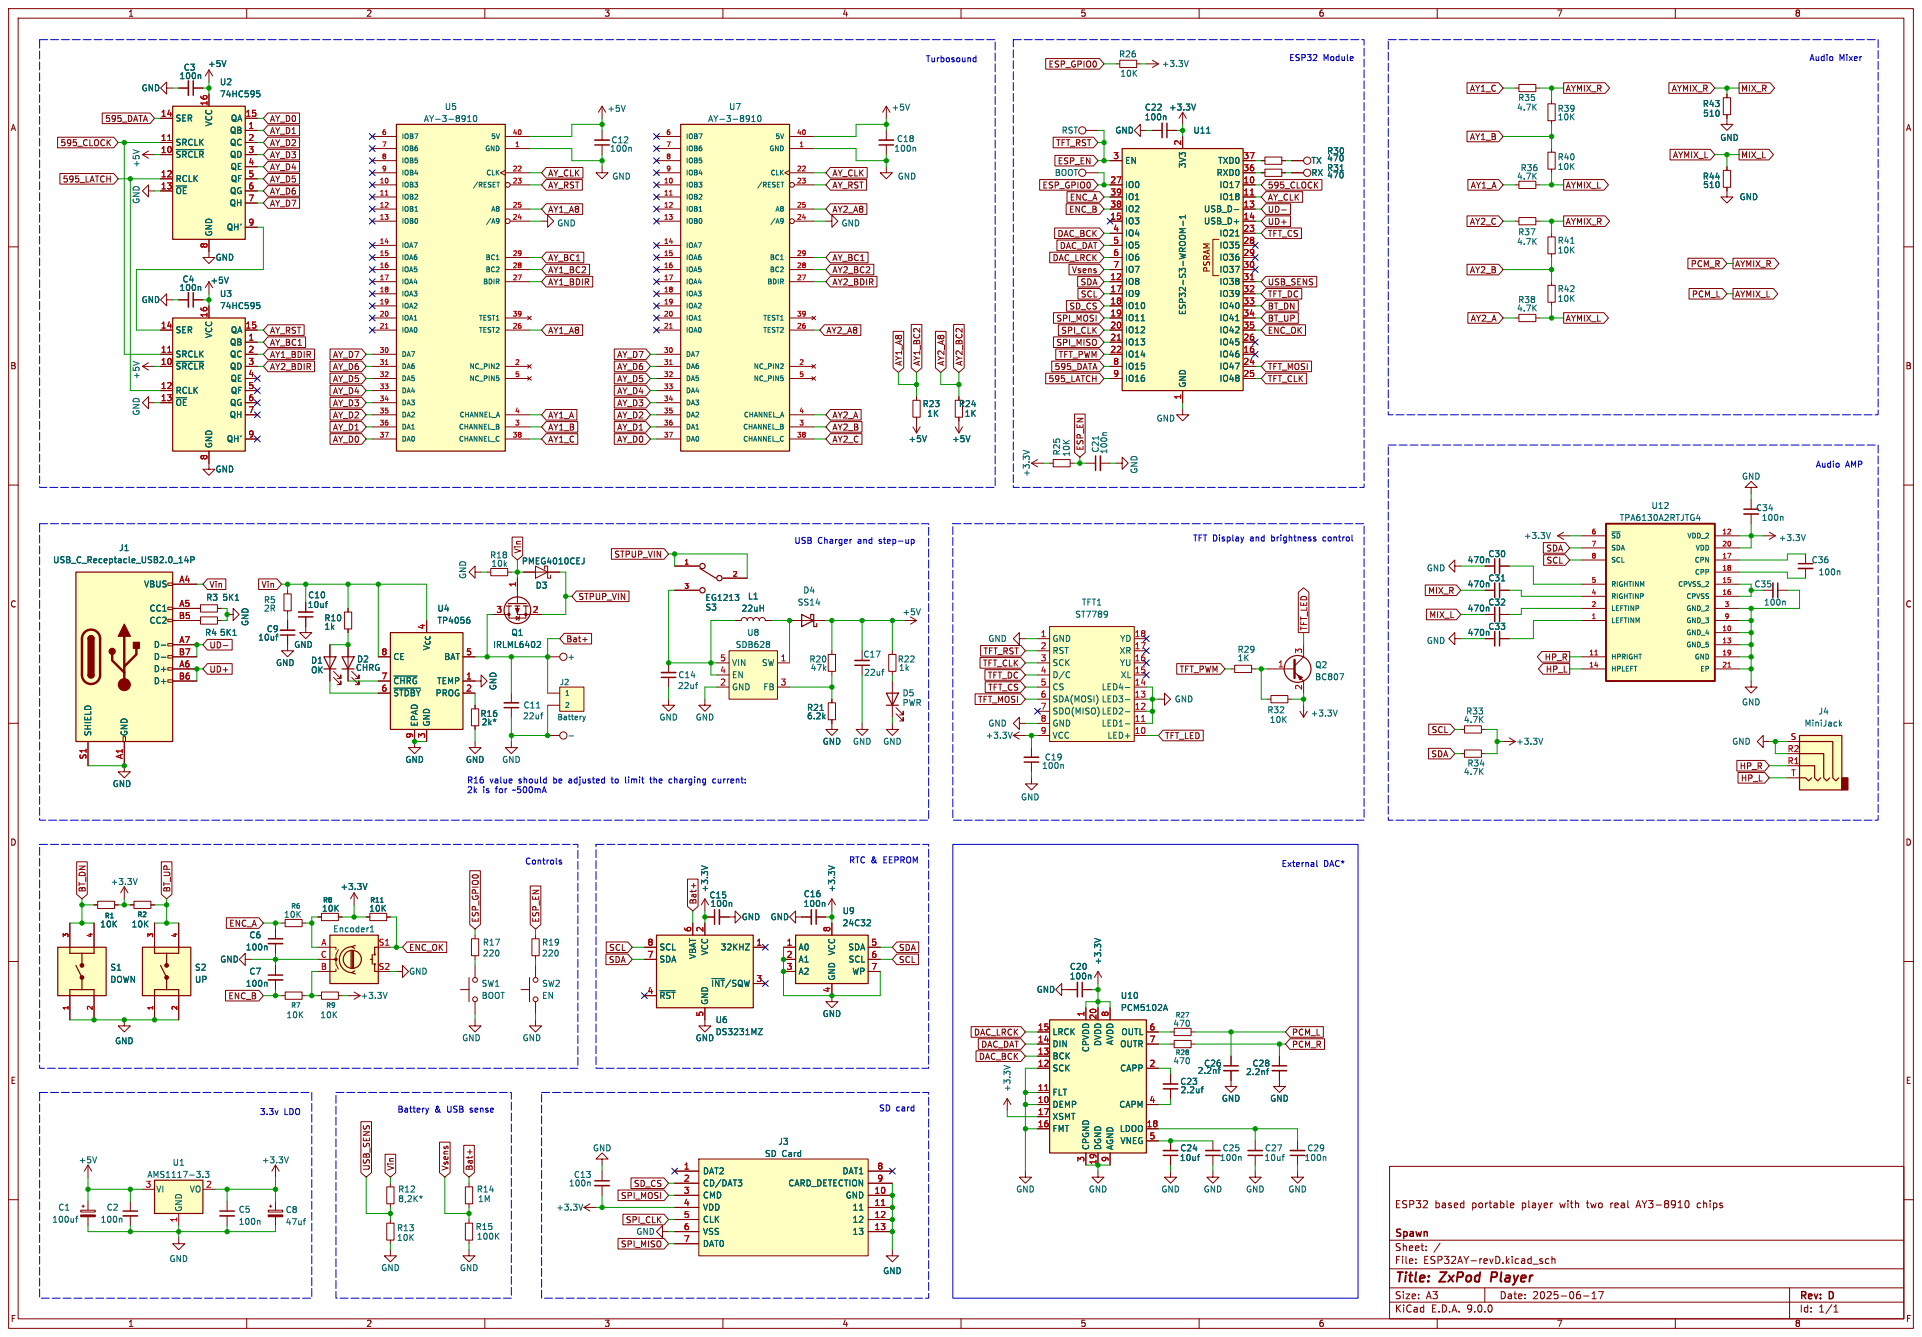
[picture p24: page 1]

8 QA 15 QB 1 QC 2 QD 3 QE 4 QF 5 QG 6 QH 7 QH' 9 GND

3 BAT 5 TEMP 1 PROG 2 GND

4 S2UP GND GND D1 OK D2 CHRG

4 SDA 5 SCL 6 WP 7 +3.3V GND

9 OUTL 6 OUTR 7 CAPP 2 CAPM 4

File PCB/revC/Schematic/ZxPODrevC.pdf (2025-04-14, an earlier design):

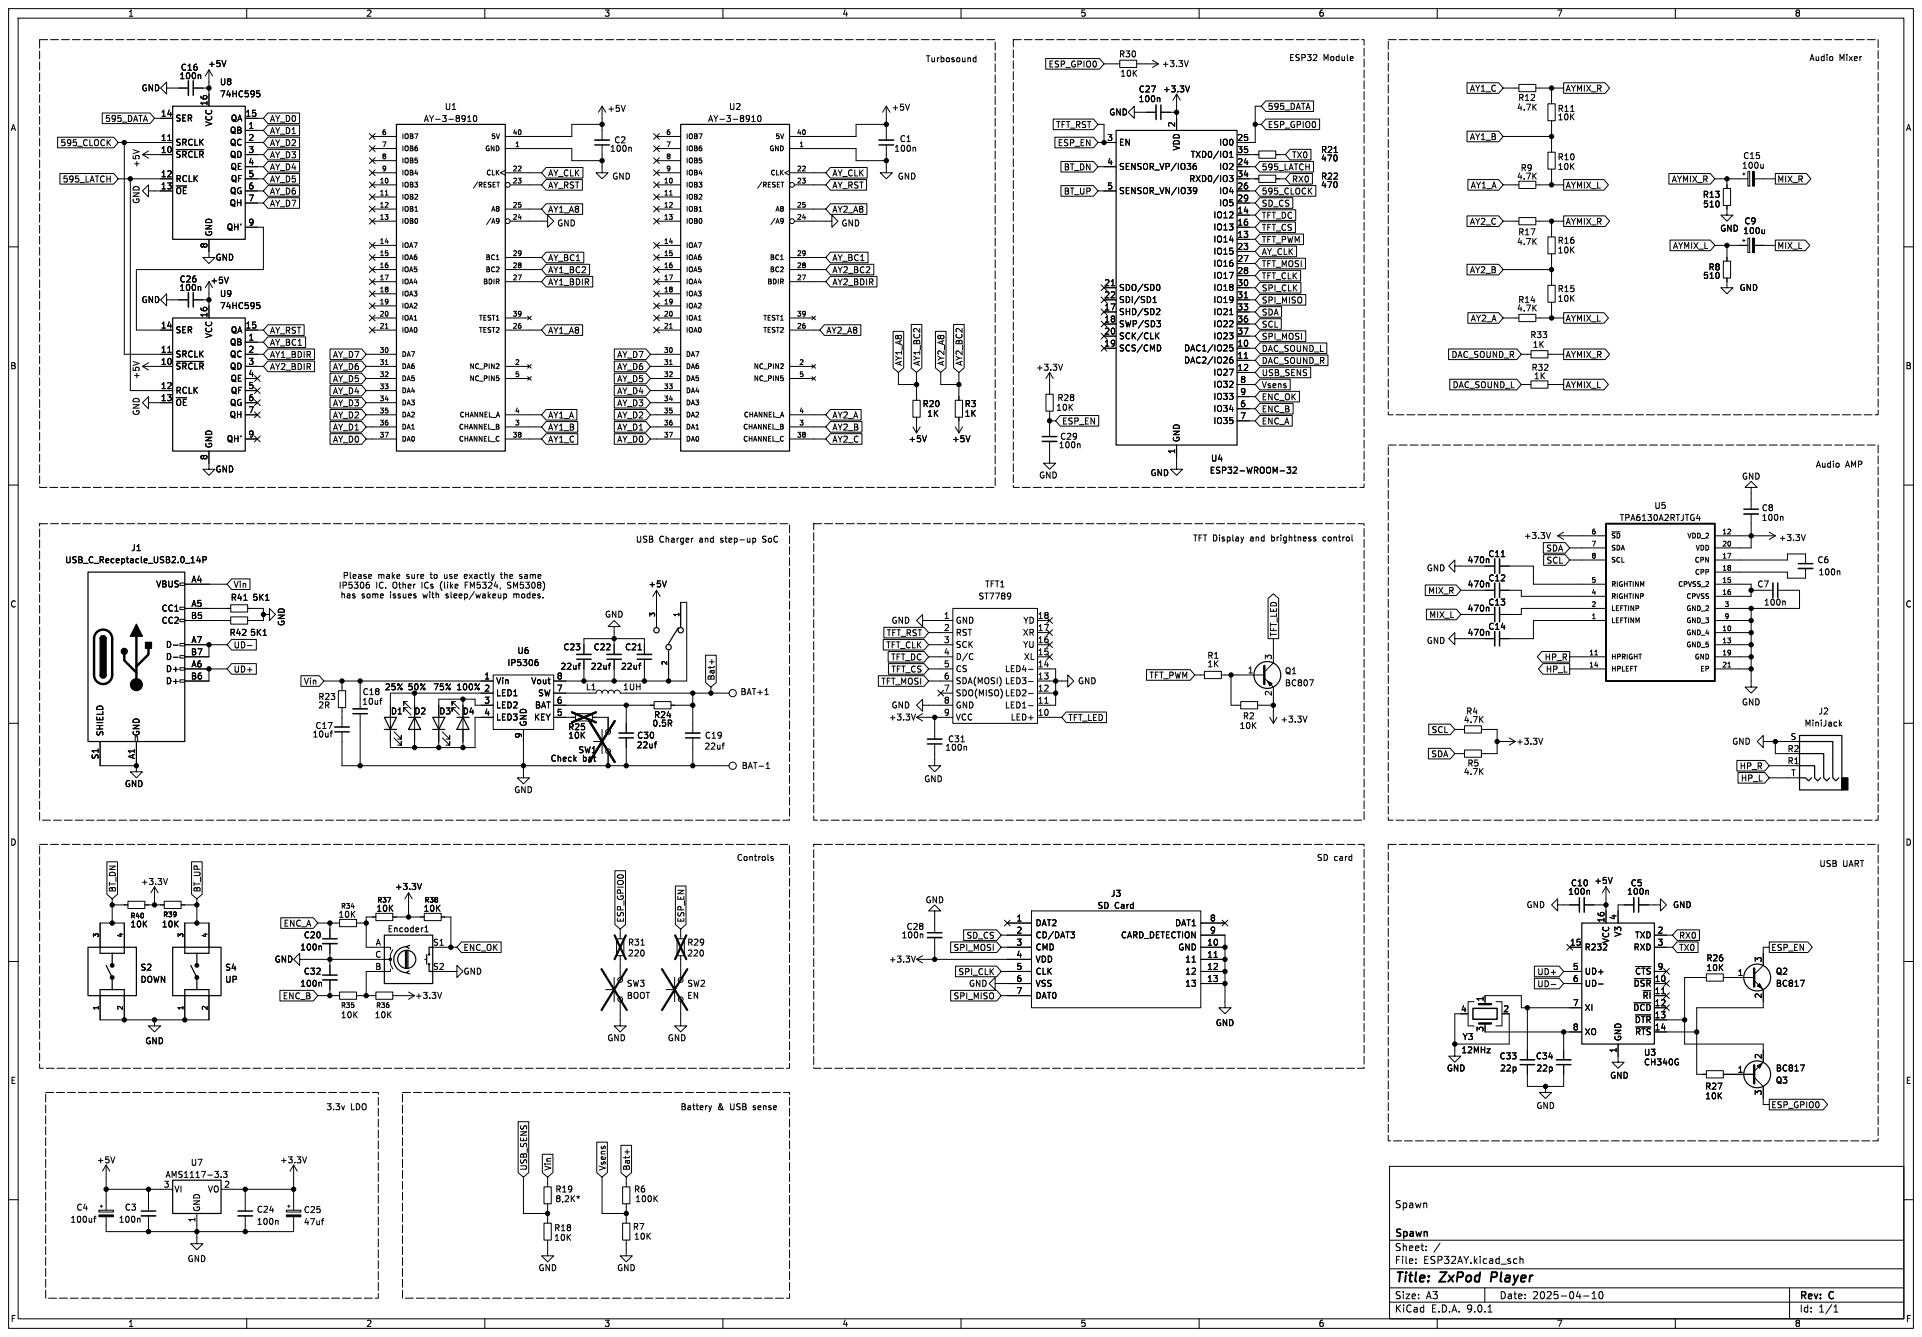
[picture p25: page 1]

Vsens ENC_OK
3 ~{CTS}9 ~{DSR} 10 ~{RI} 11 ~{DCD} 12 ~{DTR} 13 ~{RTS} 14 +5V C12

Please make sure to use exactly the same

USB UART Controls Battery & USB sense

3 ~{CTS}9 ~{DSR} 10 ~{RI} 11 ~{DCD} 12 ~{DTR} 13 ~{RTS} 14 U3 CH340G

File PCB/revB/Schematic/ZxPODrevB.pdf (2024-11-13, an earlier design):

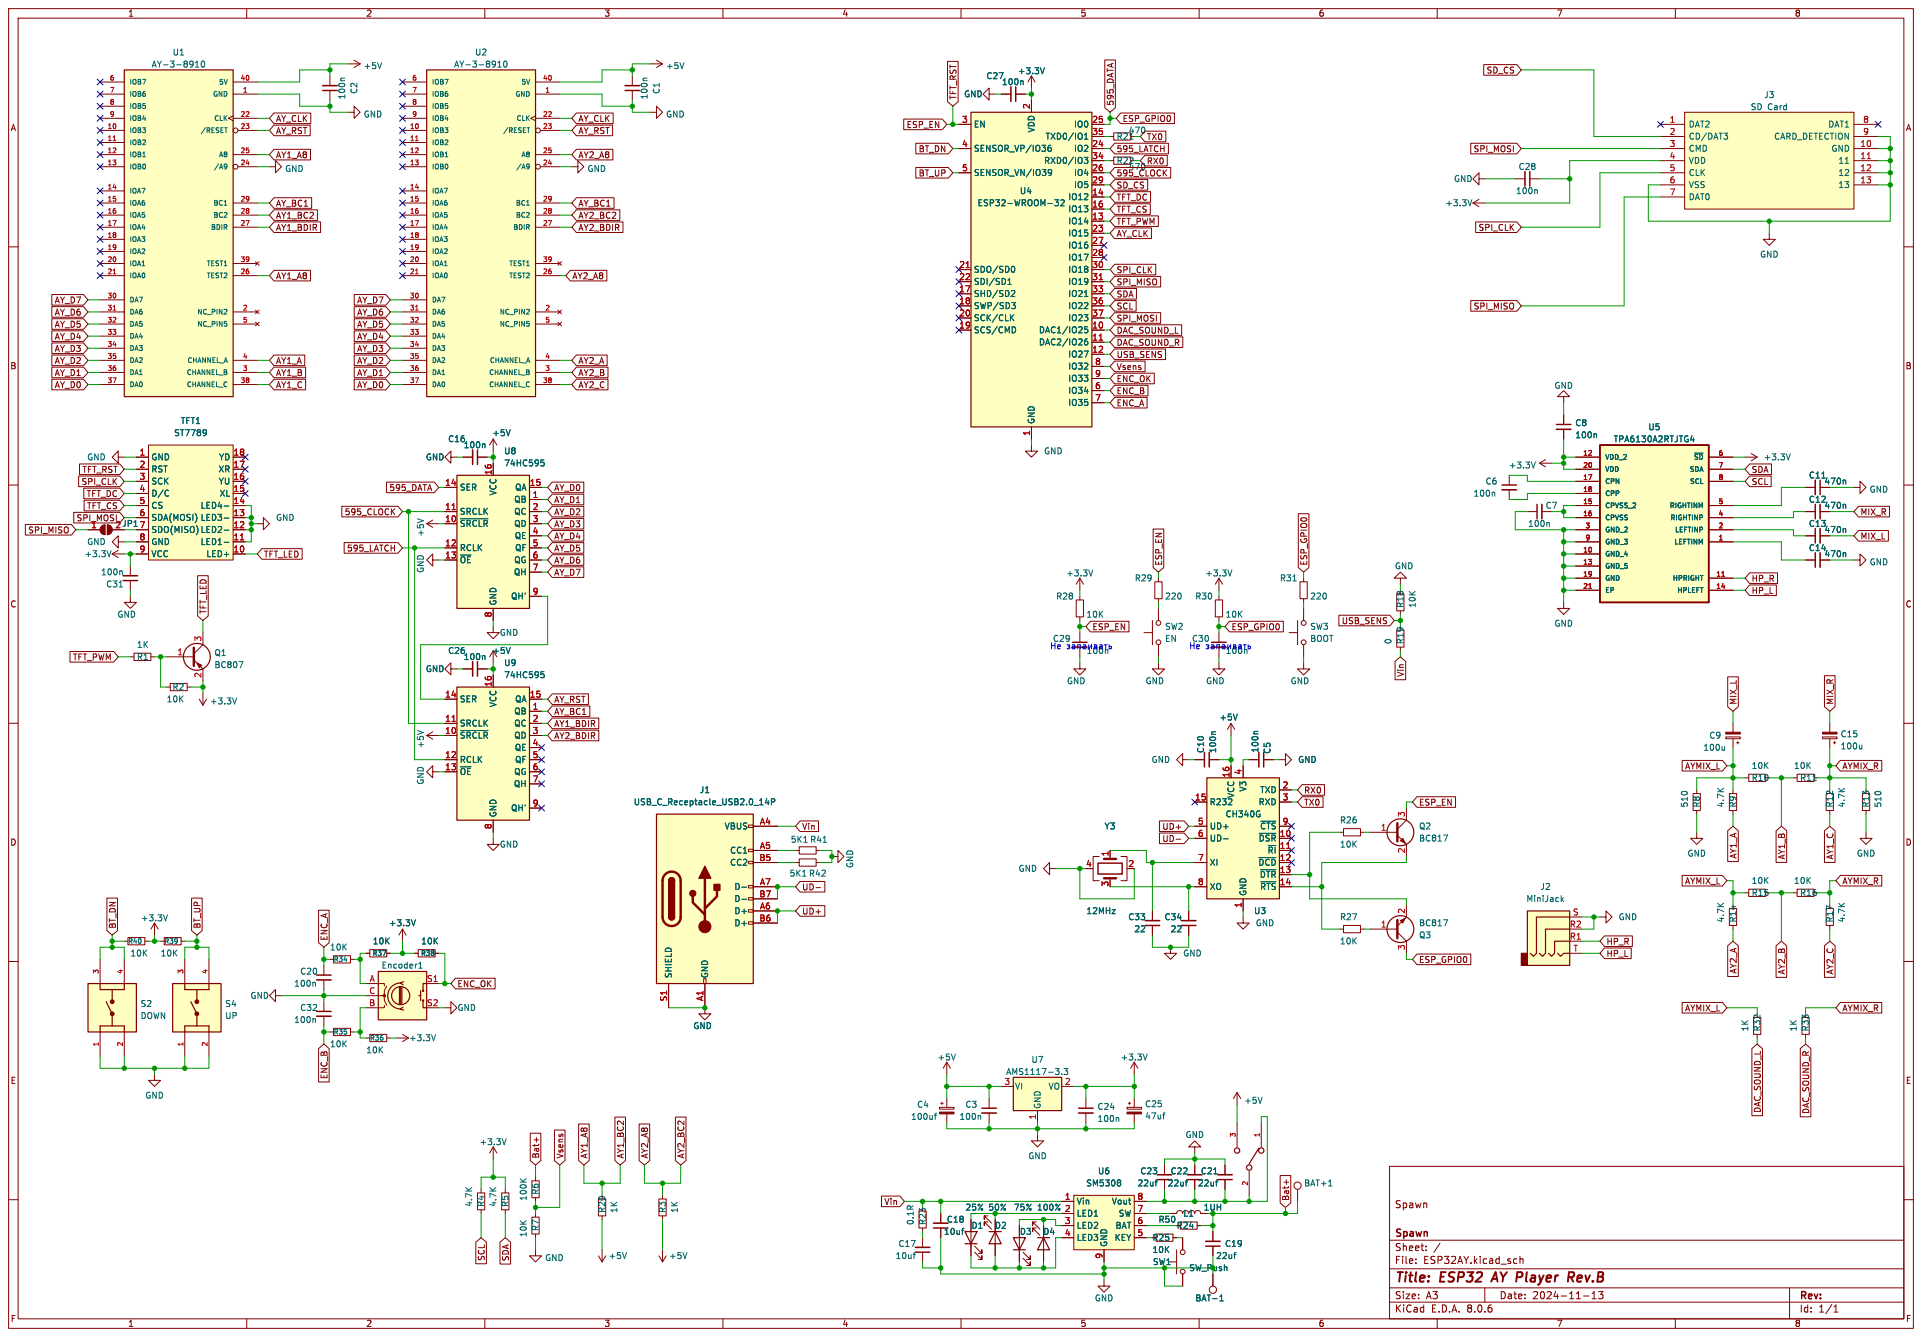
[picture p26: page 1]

2 SCK/CLK 20 SDO/SD0 21 SDI/SD1 22

1 ~{DSR} 10 ~{RI} 11 ~{DCD} 12 ~{DTR} 13 ~{RTS} 14 R232 15 VCC 16 TXD 2 RXD 3 V3

4 UD+ 5 UD- 6 XI 7 XO 8 ~{CTS}9 U3 CH340G

Id: 1/1 Title: ESP32 AY Player Rev.B

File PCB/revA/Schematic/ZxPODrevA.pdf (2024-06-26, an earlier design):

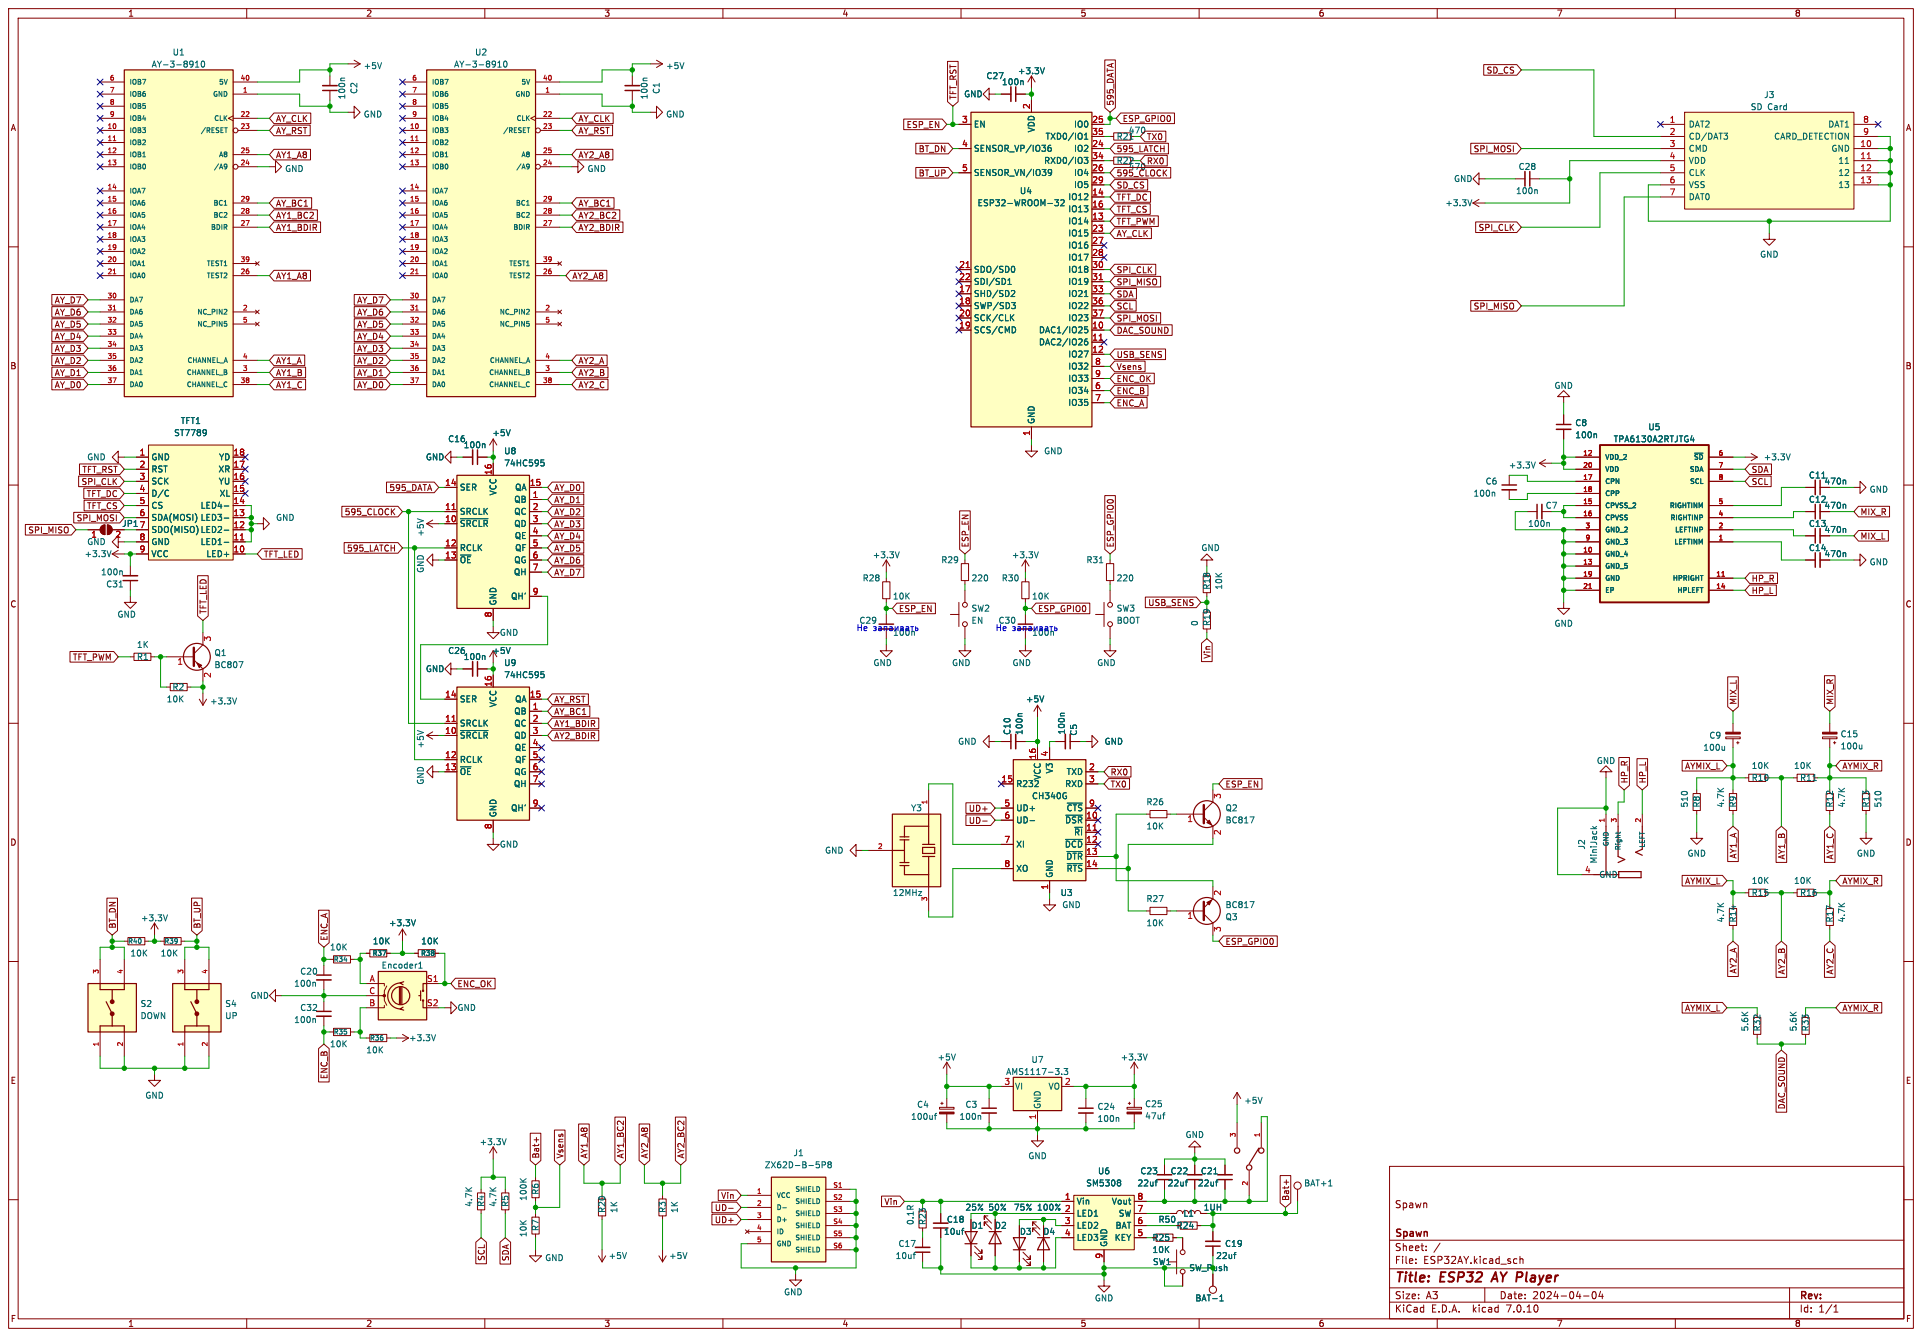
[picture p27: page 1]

2 SCK/CLK 20 SDO/SD0 21 SDI/SD1 22

4 UD+ 5 UD- 6 XI 7 XO 8 ~{CTS}9 U3 CH340G GND

GND GND 1
LED4- 14 XL 15 YU 16 XR 17 YD 18 RST 2 SCK 3 D/C 4 CS 5 SDA(MOSI) 6 SDO(MISO) 7 GND 8 VCC 9

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

4 UD+ 5 UD- 6 XI 7 XO 8 ~{CTS}9 C21

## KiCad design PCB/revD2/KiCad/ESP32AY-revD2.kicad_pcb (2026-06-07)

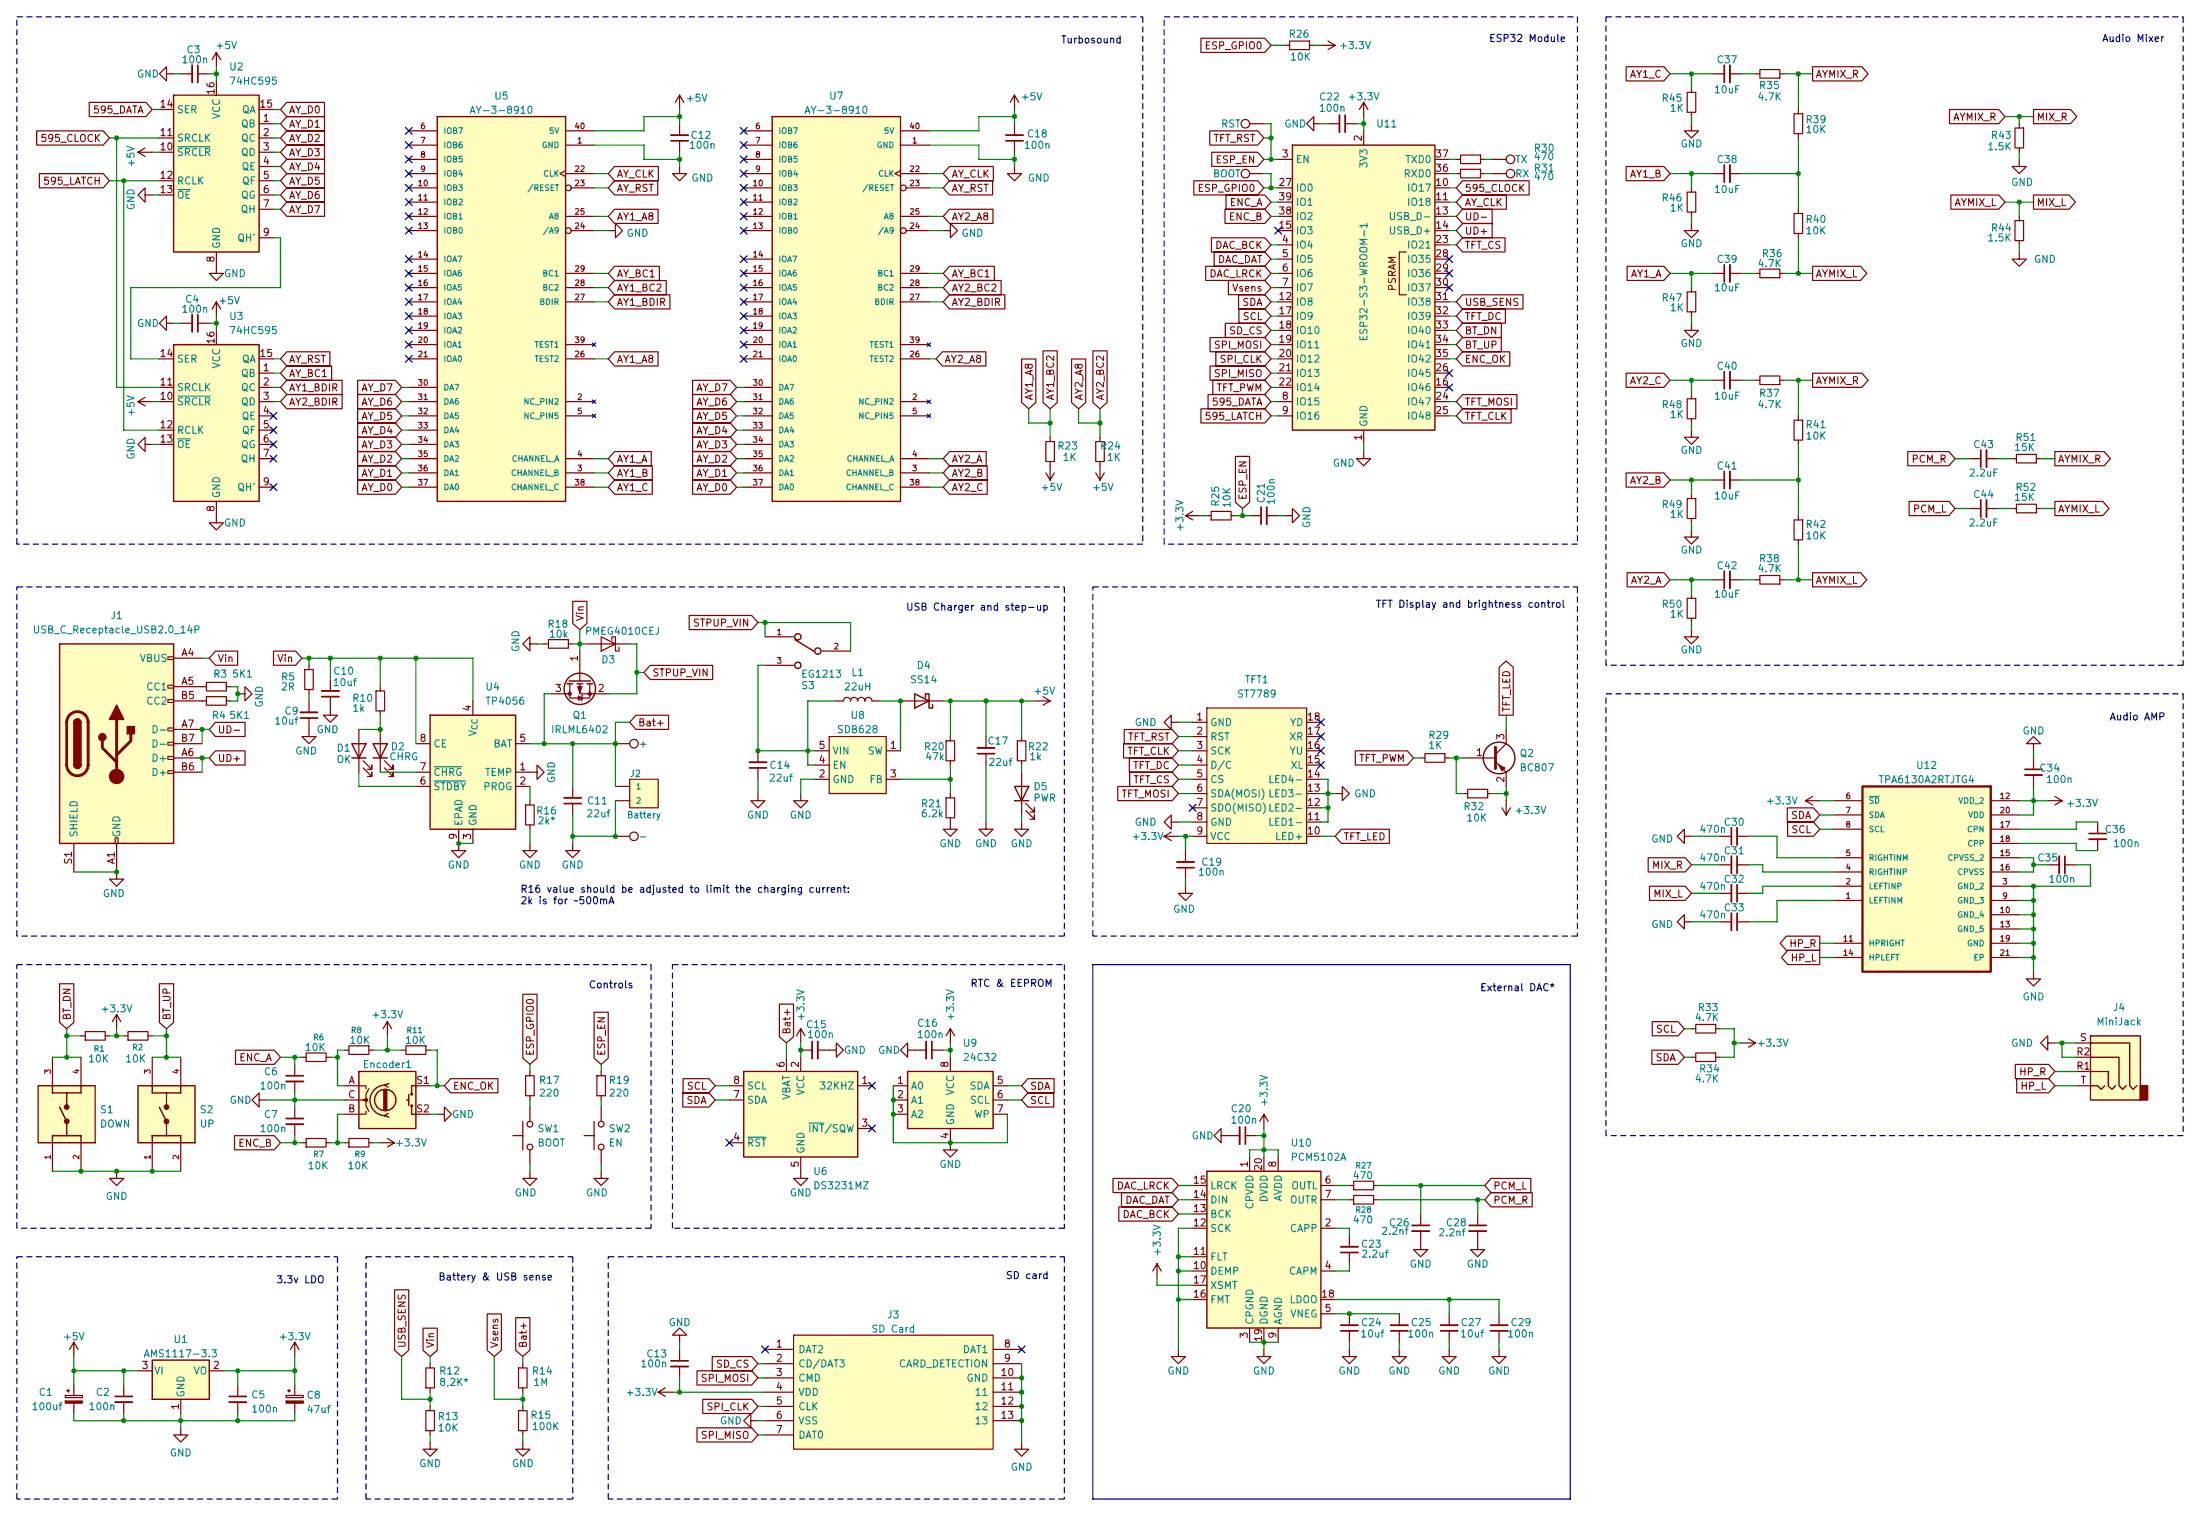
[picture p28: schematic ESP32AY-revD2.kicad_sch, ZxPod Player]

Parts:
BAT+1: +; TestPoint_Pad_D3.0mm
BAT-1: -; TestPoint_Pad_D3.0mm
BOOT1: BOOT; TestPoint_Pad_D1.0mm
C1: 100uf; CP_EIA-7343-31_Kemet-D-uni
C2, C3, C4, C5, C6, C7, C12, C13, C15, C16, C18, C19, C20, C21, C22, C25, C29, C34, C35, C36: 100n; C_0805_2012Metric_Pad1.18x1.45mm_HandSolder
C8: 47uf; CP_EIA-7343-31_Kemet-D-uni
C9, C10, C24, C27: 10uf; C_0805_2012Metric_Pad1.18x1.45mm_HandSolder
C11, C14, C17: 22uf; C_1206_3216Metric_Pad1.33x1.80mm_HandSolder
C23: 2.2uf; C_0805_2012Metric_Pad1.18x1.45mm_HandSolder
C26, C28: 2.2nf; C_0805_2012Metric_Pad1.18x1.45mm_HandSolder
C30, C31, C32, C33: 470n; C_0805_2012Metric_Pad1.18x1.45mm_HandSolder
C37, C38, C39, C40, C41, C42: 10uF; C_0805_2012Metric_Pad1.18x1.45mm_HandSolder
C43, C44: 2.2uF; C_0805_2012Metric_Pad1.18x1.45mm_HandSolder
D1: OK; LED_0805_2012Metric
D2: CHRG; LED_0805_2012Metric
D3: PMEG4010CEJ; D_SOD-323F
D4: SS14; D_SMA
D5: PWR; LED_0805_2012Metric
Encoder1: RotaryEncoder_Switch; RotaryEncoder_Alps_EC11E-Switch_Vertical_H20mm
J1: USB_C_Receptacle_USB2.0_14P; USB_C_Receptacle_G-Switch_GT-USB-7010ASV
J2: Battery; JST_PH_S2B-PH-K_1x02_P2.00mm_Horizontal
J3: SD Card; TFP09212B; Manufacturer_Part_Number TFP09-2-12B
J4: MiniJack; AUDIO_JACK_3.5MM_SMD_TRRS_rounded_mixed
L1: 22uH; L_Bourns_SRN8040TA
Q1: IRLML6402; SOT-23
Q2: BC807; SOT-23
R1, R2, R6, R7, R8, R9, R11, R13, R25, R26, R32, R39, R40, R41, R42: 10K; R_0805_2012Metric_Pad1.20x1.40mm_HandSolder
R3, R4: 5K1; R_0805_2012Metric_Pad1.20x1.40mm_HandSolder
R5: 2R; R_0805_2012Metric_Pad1.20x1.40mm_HandSolder
R10, R22: 1k; R_0805_2012Metric_Pad1.20x1.40mm_HandSolder
R12: 8,2К*; R_0805_2012Metric_Pad1.20x1.40mm_HandSolder
R14: 1M; R_0805_2012Metric_Pad1.20x1.40mm_HandSolder
R15: 100K; R_0805_2012Metric_Pad1.20x1.40mm_HandSolder
R16: 2k*; R_0805_2012Metric_Pad1.20x1.40mm_HandSolder
R17, R19: 220; R_0805_2012Metric_Pad1.20x1.40mm_HandSolder
R18: 10k; R_0805_2012Metric_Pad1.20x1.40mm_HandSolder
R20: 47k; R_0805_2012Metric_Pad1.20x1.40mm_HandSolder
R21: 6.2k; R_0805_2012Metric_Pad1.20x1.40mm_HandSolder
R23, R24, R29, R45, R46, R47, R48, R49, R50: 1K; R_0805_2012Metric_Pad1.20x1.40mm_HandSolder
R27, R28, R30, R31: 470; R_0805_2012Metric_Pad1.20x1.40mm_HandSolder
R33, R34, R35, R36, R37, R38: 4.7K; R_0805_2012Metric_Pad1.20x1.40mm_HandSolder
R43, R44: 1.5K; R_0805_2012Metric_Pad1.20x1.40mm_HandSolder
R51, R52: 15K; R_0805_2012Metric_Pad1.20x1.40mm_HandSolder
RST1: RST; TestPoint_Pad_D1.0mm
RX1: RX; TestPoint_Pad_D1.0mm
S1: DOWN; SW_Push_1P1T_NO_6x6mm_H9.5mm
S2: UP; SW_Push_1P1T_NO_6x6mm_H9.5mm
S3: EG1213; SW_EG1213
SW1: BOOT; SW_SPST_PTS810_handsoldering
SW2: EN; SW_SPST_PTS810_handsoldering
TFT1: ST7789
TX1: TX; TestPoint_Pad_D1.0mm
U1: AMS1117-3.3; SOT-223-3_TabPin2
U2, U3: 74HC595; SO-16_3.9x9.9mm_P1.27mm
U4: TP4056; SOIC-8-1EP_3.9x4.9mm_P1.27mm_EP2.41x3.3mm_ThermalVias
U5, U7: AY-3-8910; DIP-40_W15.24mm_Socket
U6: DS3231MZ; SOIC-8_3.9x4.9mm_P1.27mm
U8: SDB628; SOT-23-6_Handsoldering
U9: 24С32; SOIC-8_3.9x4.9mm_P1.27mm
U10: PCM5102A; TSSOP-20_4.4x6.5mm_P0.65mm
U11: ESP32-S3-WROOM-1
U12: TPA6130A2RTJTG4; QFN50P400X400X80-21N; MPN TPA6130A2RTJTG4

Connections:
595_CLOCK: U2.11 (SRCLK), U3.11 (SRCLK), U11.10 (IO17)
595_DATA: U2.14 (SER), U11.8 (IO15)
595_LATCH: U2.12 (RCLK), U3.12 (RCLK), U11.9 (IO16)
+3.3V: C5.1, C8.1, C13.2, C15.1, C16.1, C19.2, C20.1, C22.1, C34.2, J3.4 (VDD), Q2.2 (E), R1.2, R2.1, R8.1, R9.2, R11.2, R25.1, R26.1, R32.2, R33.1, R34.1, TFT1.9 (VCC), U1.2 (VO), U6.2 (VCC), U9.8 (VCC), U10.1 (CPVDD), U10.8 (AVDD), U10.17 (XSMT), U10.20 (DVDD), U11.2 (3V3), U12.6 (~SD), U12.12 (VDD_2), U12.20 (VDD)
+5V: C1.1, C2.1, C3.1, C4.1, C12.2, C17.2, C18.2, D4.1 (K), R20.1, R22.1, R23.2, R24.2, U1.3 (VI), U2.10 (~SRCLR), U2.16 (VCC), U3.10 (~SRCLR), U3.16 (VCC), U5.40 (5V), U7.40 (5V)
AY1_A: C39.1, R47.1, U5.4 (CHANNEL_A)
AY1_A8: R23.1, U5.25 (A8), U5.26 (TEST2), U5.28 (BC2)
AY1_B: C38.1, R46.1, U5.3 (CHANNEL_B)
AY1_BDIR: U3.2 (QC), U5.27 (BDIR)
AY1_C: C37.1, R45.1, U5.38 (CHANNEL_C)
AY2_A: C42.1, R50.1, U7.4 (CHANNEL_A)
AY2_A8: R24.1, U7.25 (A8), U7.26 (TEST2), U7.28 (BC2)
AY2_B: C41.1, R49.1, U7.3 (CHANNEL_B)
AY2_BDIR: U3.3 (QD), U7.27 (BDIR)
AY2_C: C40.1, R48.1, U7.38 (CHANNEL_C)
AY_BC1: U3.1 (QB), U5.29 (BC1), U7.29 (BC1)
AY_CLK: U5.22 (CLK), U7.22 (CLK), U11.11 (IO18)
AY_D0: U2.15 (QA), U5.37 (DA0), U7.37 (DA0)
AY_D1: U2.1 (QB), U5.36 (DA1), U7.36 (DA1)
AY_D2: U2.2 (QC), U5.35 (DA2), U7.35 (DA2)
AY_D3: U2.3 (QD), U5.34 (DA3), U7.34 (DA3)
AY_D4: U2.4 (QE), U5.33 (DA4), U7.33 (DA4)
AY_D5: U2.5 (QF), U5.32 (DA5), U7.32 (DA5)
AY_D6: U2.6 (QG), U5.31 (DA6), U7.31 (DA6)
AY_D7: U2.7 (QH), U5.30 (DA7), U7.30 (DA7)
AY_RST: U3.15 (QA), U5.23 (/RESET), U7.23 (/RESET)
BT_DN: R1.1, S1.3, S1.4, U11.33 (IO40)
BT_UP: R2.2, S2.3, S2.4, U11.34 (IO41)
Bat+: BAT+1.1 (1_1), C11.2, J2.1, Q1.3 (D), R14.1, U4.5 (BAT), U6.6 (VBAT)
DAC_BCK: U10.13 (BCK), U11.4 (IO4)
DAC_DAT: U10.14 (DIN), U11.5 (IO5)
DAC_LRCK: U10.15 (LRCK), U11.6 (IO6)
ENC_A: C6.1, R6.1, U11.39 (IO1)
ENC_B: C7.2, R7.1, U11.38 (IO2)
ENC_OK: Encoder1.S1, R11.1, U11.35 (IO42)
ESP_EN: C21.1, R19.1, R25.2, RST1.1 (1_1), TFT1.2 (RST), U11.3 (EN)
ESP_GPIO0: BOOT1.1 (1_1), R17.1, R26.2, U11.27 (IO0)
GND: BAT-1.1 (1_1), C1.2, C2.2, C3.2, C4.2, C5.2, C6.2, C7.1, C8.2, C9.1, C10.1, C11.1, C12.1, C13.1, C14.1, C15.2, C16.2, C17.1, C18.1, C19.1, C20.2, C21.2, C22.2, C24.1, C25.1, C26.2, C27.1, C28.2, C29.1, C30.1, C33.2, C34.1, C35.1, D5.1 (K), Encoder1.C, Encoder1.MP, Encoder1.S2, J1.A1 (GND), J1.A12 (GND), J1.B1 (GND), J1.B12 (GND), J1.S1 (SHIELD), J2.2, J3.6 (VSS), J3.9 (CARD_DETECTION), J3.10 (GND), J3.11, J3.12, J3.13, J4.R2, J4.S, R3.2, R4.2, R13.1, R15.2, R16.2, R18.2, R21.2, R43.2, R44.2, R45.2, R46.2, R47.2, R48.2, R49.2, R50.2, S1.1, S1.2, S2.1, S2.2, SW1.1 (A), SW2.1 (A), TFT1.1 (GND), TFT1.8 (GND), TFT1.11 (LED1-), TFT1.12 (LED2-), TFT1.13 (LED3-), TFT1.14 (LED4-), U1.1 (GND), U2.8 (GND), U2.13 (~OE), U3.8 (GND), U3.13 (~OE), U4.1 (TEMP), U4.3 (GND), U4.9 (EPAD), U5.1 (GND), U5.24 (/A9), U6.5 (GND), U7.1 (GND), U7.24 (/A9), U8.2 (GND), U9.1 (A0), U9.2 (A1), U9.3 (A2), U9.4 (GND), U9.7 (WP), U10.3 (CPGND), U10.9 (AGND), U10.10 (DEMP), U10.11 (FLT), U10.12 (SCK), U10.16 (FMT), U10.19 (DGND), U11.1 (GND), U11.40 (GND), U11.41 (GND), U12.3 (GND_2), U12.9 (GND_3), U12.10 (GND_4), U12.13 (GND_5), U12.19 (GND), U12.21 (EP)
HP_L: J4.T, U12.14 (HPLEFT)
HP_R: J4.R1, U12.11 (HPRIGHT)
unnamed: C9.2, R5.2
unnamed: C37.2, R35.2
unnamed: C38.2, R39.2, R40.1
unnamed: C39.2, R36.2
unnamed: C40.2, R37.2
unnamed: C41.2, R41.2, R42.1
unnamed: C42.2, R38.2
unnamed: C43.2, R51.2
unnamed: C44.2, R52.2
unnamed: D1.2 (A), D2.2 (A), R10.2
unnamed: D1.1 (K), U4.6 (~STDBY)
unnamed: D2.1 (K), U4.7 (~CHRG)
unnamed: D4.2 (A), L1.2, U8.1 (SW)
unnamed: D5.2 (A), R22.2
unnamed: Encoder1.A, R6.2, R8.2
unnamed: Encoder1.B, R7.2, R9.1
unnamed: J1.A5 (CC1), R3.1
unnamed: J1.B5 (CC2), R4.1
unnamed: Q2.1 (B), R29.1, R32.1
unnamed: R30.1, TX1.1 (1_1)
unnamed: R31.1, RX1.1 (1_1)
unnamed: R17.2, SW1.2 (B)
unnamed: R19.2, SW2.2 (B)
unnamed: U2.9 (QH'), U3.14 (SER)
unnamed: R16.1, U4.2 (PROG)
unnamed: C14.2, L1.1, S3.3, U8.4 (EN), U8.5 (VIN)
unnamed: R20.2, R21.1, U8.3 (FB)
unnamed: C23.1, U10.4 (CAPM)
unnamed: C23.2, U10.2 (CAPP)
unnamed: C27.2, C29.2, U10.18 (LDOO)
unnamed: R27.1, U10.6 (OUTL)
unnamed: R28.1, U10.7 (OUTR)
unnamed: C24.2, C25.2, U10.5 (VNEG)
unnamed: R31.2, U11.36 (RXD0)
unnamed: R30.2, U11.37 (TXD0)
unnamed: C36.1, U12.17 (CPN)
unnamed: C36.2, U12.18 (CPP)
unnamed: C35.2, U12.15 (CPVSS_2), U12.16 (CPVSS)
unnamed: C33.1, U12.1 (LEFTINM)
unnamed: C32.1, U12.2 (LEFTINP)
unnamed: C30.2, U12.5 (RIGHTINM)
unnamed: C31.1, U12.4 (RIGHTINP)
SCL: R33.2, U6.8 (SCL), U9.6 (SCL), U11.17 (IO9), U12.8 (SCL)
SDA: R34.2, U6.7 (SDA), U9.5 (SDA), U11.12 (IO8), U12.7 (SDA)
SD_CS: J3.2 (CD/DAT3), U11.18 (IO10)
SPI_CLK: J3.5 (CLK), U11.20 (IO12)
SPI_MISO: J3.7 (DAT0), U11.21 (IO13)
SPI_MOSI: J3.3 (CMD), U11.19 (IO11)
STPUP_VIN: D3.1 (K), Q1.2 (S), S3.1, S3.2
TFT_CLK: TFT1.3 (SCK), U11.25 (IO48)
TFT_CS: TFT1.5 (CS), U11.23 (IO21)
TFT_DC: TFT1.4 (D/C), U11.32 (IO39)
TFT_LED: Q2.3 (C), TFT1.10 (LED+)
TFT_MOSI: TFT1.6 (SDA(MOSI)), U11.24 (IO47)
TFT_PWM: R29.2, U11.22 (IO14)
UD+: J1.A6 (D+), J1.B6 (D+), U11.14 (USB_D+)
UD-: J1.A7 (D-), J1.B7 (D-), U11.13 (USB_D-)
USB_SENS: R12.1, R13.2, U11.31 (IO38)
Vin: C10.2, D3.2 (A), J1.A4 (VBUS), J1.A9 (VBUS), J1.B4 (VBUS), J1.B9 (VBUS), Q1.1 (G), R5.1, R10.1, R12.2, R18.1, U4.4 (V_{CC}), U4.8 (CE)
Vsens: R14.2, R15.1, U11.7 (IO7)

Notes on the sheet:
Battery & USB sense
TFT Display and brightness control
ESP32 Module
RTC & EEPROM
SD card
Turbosound
Audio AMP
External DAC*
USB Charger and step-up
3.3v LDO
R16 value should be adjusted to limit the charging current: 2k is for ~500mA
Controls
Audio Mixer

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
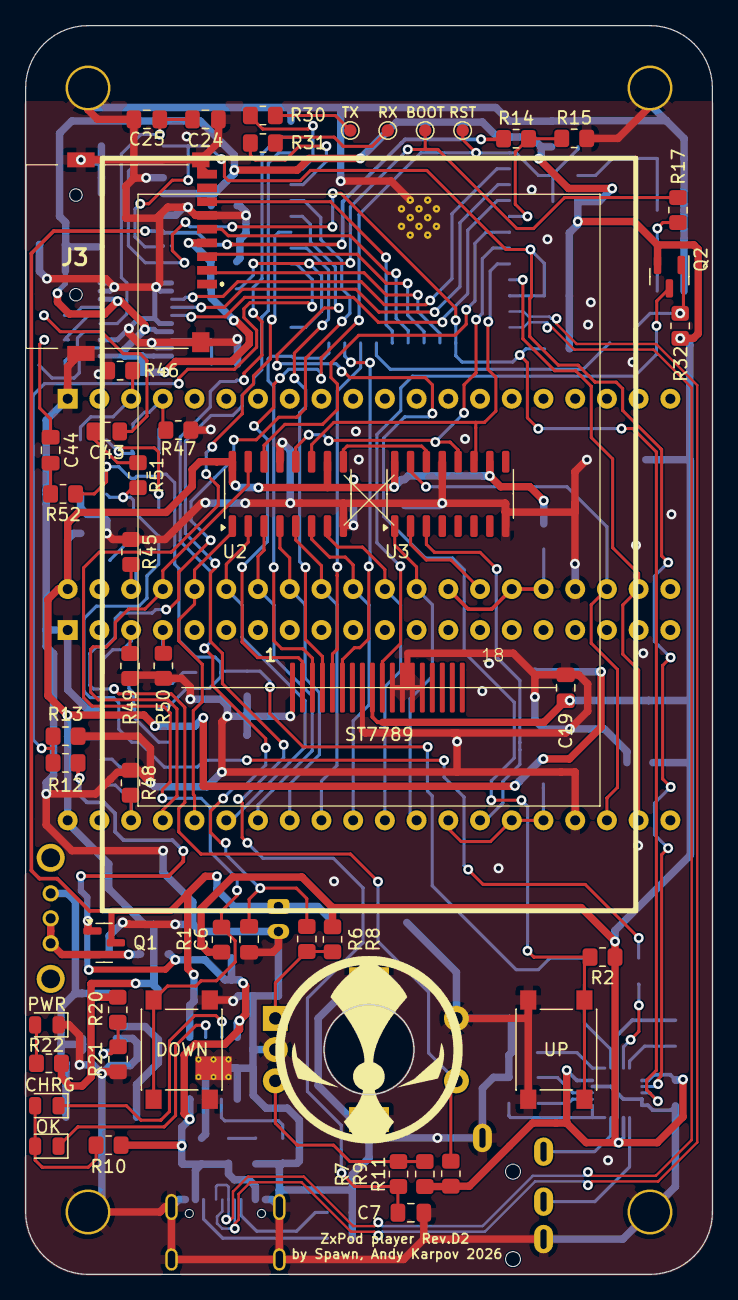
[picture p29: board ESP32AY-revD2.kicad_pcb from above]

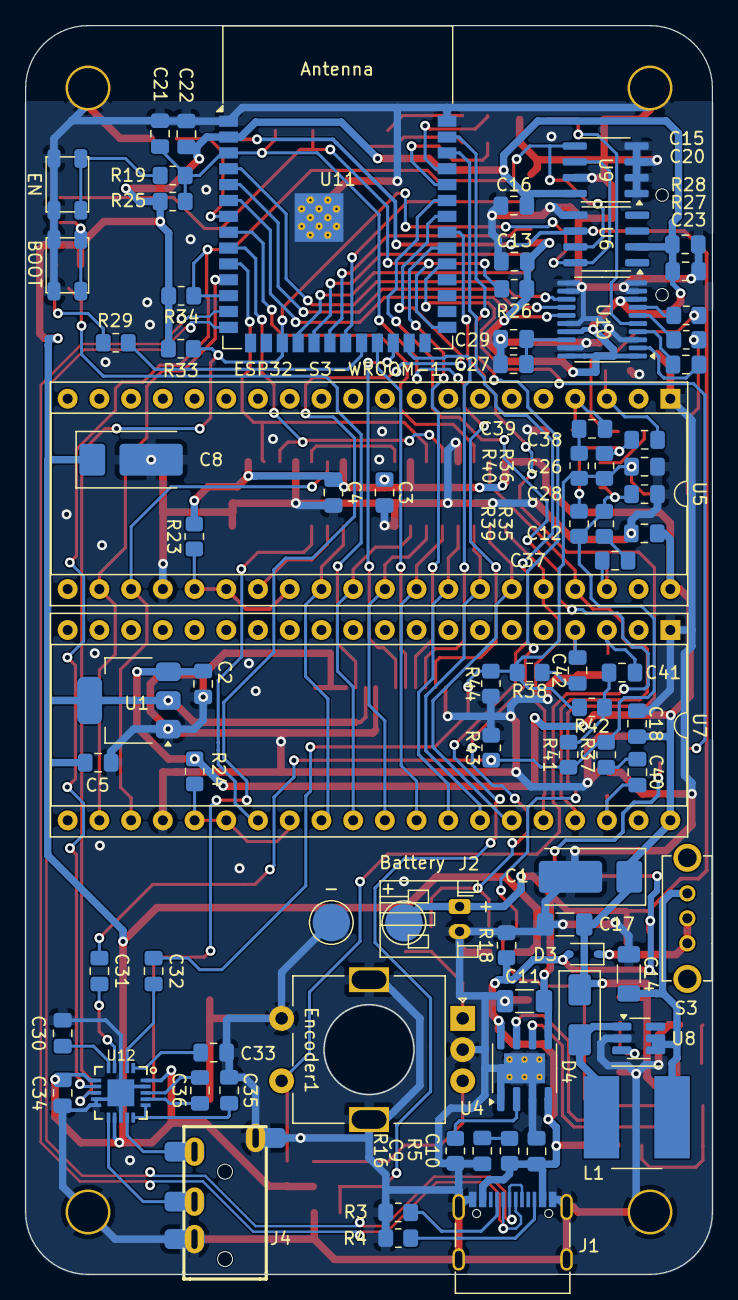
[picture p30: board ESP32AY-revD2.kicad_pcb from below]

Board: 2 copper layers, 55.0 x 100.0 mm, 133 parts (83 on the bottom side), 104 nets.

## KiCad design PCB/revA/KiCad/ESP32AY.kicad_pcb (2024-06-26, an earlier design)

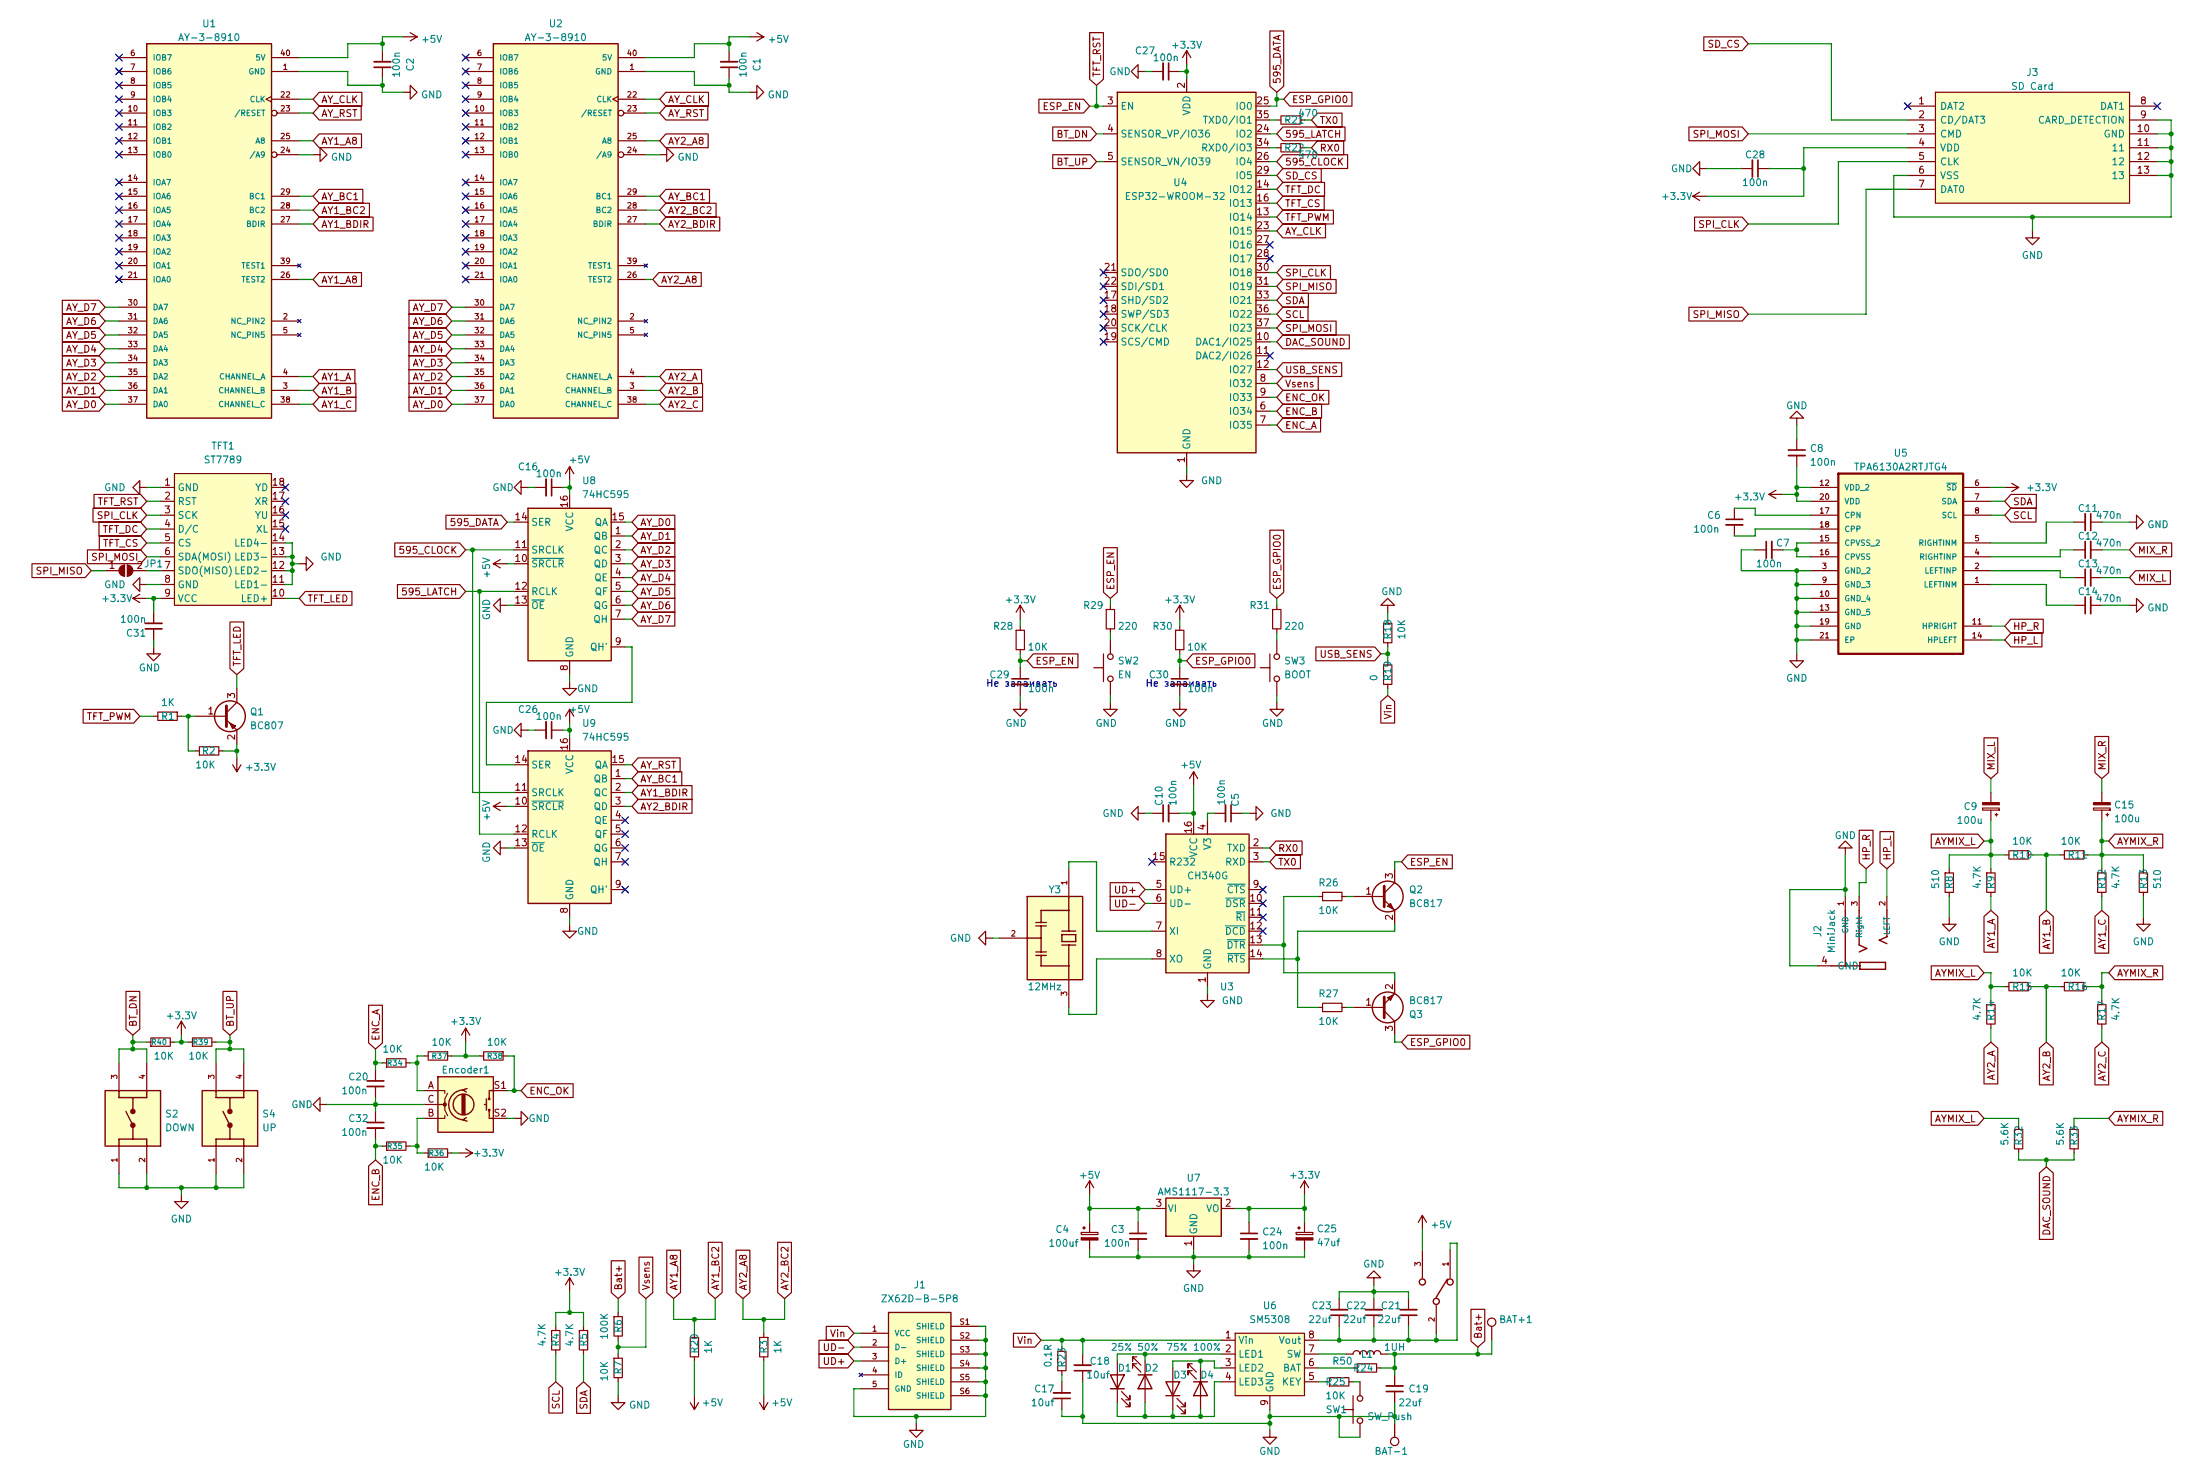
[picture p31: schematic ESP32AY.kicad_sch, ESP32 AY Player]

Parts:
BAT+1: BAT+; TestPoint_Pad_D3.0mm
BAT-1: BAT-; TestPoint_Pad_D3.0mm
C1, C2, C3, C5, C6, C7, C8, C10, C16, C20, C24, C26, C27, C28, C29, C30, C31, C32: 100n; C_1206_3216Metric
C4: 100uf; CP_EIA-7360-38_Kemet-E
C9, C15: 100u; CP_EIA-7360-38_Kemet-E
C11, C12, C13, C14: 470n; C_1206_3216Metric
C17, C18: 10uf; C_1206_3216Metric
C19, C21, C22: 22uf; C_1206_3216Metric
C23: 22uf; C_0805_2012Metric
C25: 47uf; CP_EIA-7360-38_Kemet-E
D1: 25%; LED_0805_2012Metric
D2: 50%; LED_0805_2012Metric
D3: 75%; LED_0805_2012Metric
D4: 100%; LED_0805_2012Metric
Encoder1: RotaryEncoder_Switch; RotaryEncoder_Alps_EC11E-Switch_Vertical_H20mm
J1: ZX62D-B-5P8; HRS_ZX62D-B-5P8; PARTREV N/A
J2: MiniJack; Jack_3.5mm_PJ320D_Horizontal; PARTREV L
J3: SD Card; TFP09212B; Manufacturer_Part_Number TFP09-2-12B
JP1: jumper; SolderJumper-2_P1.3mm_Bridged_RoundedPad1.0x1.5mm
L1: 1UH; L_7.3x7.3_H3.5
Q1: BC807; SOT-23
Q2, Q3: BC817; SOT-23
R1, R3, R20: 1K; R_1206_3216Metric
R2, R7, R10, R11, R15, R16, R18, R26, R27, R28, R30, R34, R35, R36, R37, R38, R39, R40: 10K; R_1206_3216Metric
R4, R5, R9, R12, R14, R17: 4.7K; R_1206_3216Metric
R6: 100K; R_1206_3216Metric
R8, R13: 510; R_1206_3216Metric
R19: 0; R_1206_3216Metric
R21, R22: 470; R_1206_3216Metric
R23: 0.1R; R_0805_2012Metric
R24: R50; R_0805_2012Metric
R25: 10K; R_0805_2012Metric
R29, R31: 220; R_1206_3216Metric
R32, R33: 5.6K; R_1206_3216Metric
S2: DOWN; SW_Push_1P1T_NO_6x6mm_H9.5mm
S4: UP; SW_Push_1P1T_NO_6x6mm_H9.5mm
S6: EG1213; SW_EG1213
SW1: SW_Push; SolderJumper-2_P1.3mm_Open_RoundedPad1.0x1.5mm
SW2: EN; SW_SPST_B3U-1000P
SW3: BOOT; SW_SPST_B3U-1000P
TFT1: ST7789
U1, U2: AY-3-8910; DIP-40_W15.24mm_Socket
U3: CH340G; SOIC-16_3.9x9.9mm_P1.27mm
U4: ESP32-WROOM-32
U5: TPA6130A2RTJTG4; QFN50P400X400X80-21N; MPN TPA6130A2RTJTG4
U6: SM5308; HSOP-8-1EP_3.9x4.9mm_P1.27mm_EP2.41x3.1mm
U7: AMS1117-3.3; SOT-223-3_TabPin2
U8, U9: 74HC595; SO-16_5.3x10.2mm_P1.27mm
Y3: 12MHz; OSC_CSTCE16M0V53-R0; PARTREV 10/24/2022

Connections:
595_CLOCK: U4.26 (IO4), U8.11 (SRCLK), U9.11 (SRCLK)
595_DATA: C30.1, Q3.3 (C), R30.2, R31.1, U4.25 (IO0), U8.14 (SER)
595_LATCH: U4.24 (IO2), U8.12 (RCLK), U9.12 (RCLK)
+3.3V: C8.2, C24.1, C25.1, C27.1, C28.1, C31.2, J3.4 (VDD), Q1.2 (E), R2.2, R4.1, R5.1, R28.1, R30.1, R36.2, R37.1, R38.2, R39.1, R40.2, TFT1.9 (VCC), U4.2 (VDD), U5.6 (~SD), U5.12 (VDD_2), U5.20 (VDD), U7.2 (VO)
+5V: C1.2, C2.2, C3.1, C4.1, C10.2, C16.1, C26.1, R3.2, R20.2, S6.3, U1.40 (5V), U2.40 (5V), U3.16 (VCC), U7.3 (VI), U8.10 (~SRCLR), U8.16 (VCC), U9.10 (~SRCLR), U9.16 (VCC)
AY1_A: R9.2, U1.4 (CHANNEL_A)
AY1_A8: R20.1, U1.25 (A8), U1.26 (TEST2), U1.28 (BC2)
AY1_B: R10.1, R11.2, U1.3 (CHANNEL_B)
AY1_BDIR: U1.27 (BDIR), U9.2 (QC)
AY1_C: R12.2, U1.38 (CHANNEL_C)
AY2_A: R14.2, U2.4 (CHANNEL_A)
AY2_A8: R3.1, U2.25 (A8), U2.26 (TEST2), U2.28 (BC2)
AY2_B: R15.1, R16.2, U2.3 (CHANNEL_B)
AY2_BDIR: U2.27 (BDIR), U9.3 (QD)
AY2_C: R17.2, U2.38 (CHANNEL_C)
AYMIX_L: C9.1, R8.1, R9.1, R10.2, R14.1, R15.2, R32.1
AYMIX_R: C15.1, R11.1, R12.1, R13.1, R16.1, R17.1, R33.1
AY_BC1: U1.29 (BC1), U2.29 (BC1), U9.1 (QB)
AY_CLK: U1.22 (CLK), U2.22 (CLK), U4.23 (IO15)
AY_D0: U1.37 (DA0), U2.37 (DA0), U8.15 (QA)
AY_D1: U1.36 (DA1), U2.36 (DA1), U8.1 (QB)
AY_D2: U1.35 (DA2), U2.35 (DA2), U8.2 (QC)
AY_D3: U1.34 (DA3), U2.34 (DA3), U8.3 (QD)
AY_D4: U1.33 (DA4), U2.33 (DA4), U8.4 (QE)
AY_D5: U1.32 (DA5), U2.32 (DA5), U8.5 (QF)
AY_D6: U1.31 (DA6), U2.31 (DA6), U8.6 (QG)
AY_D7: U1.30 (DA7), U2.30 (DA7), U8.7 (QH)
AY_RST: U1.23 (/RESET), U2.23 (/RESET), U9.15 (QA)
BT_DN: R40.1, S2.3, S2.4, U4.4 (SENSOR_VP/IO36)
BT_UP: R39.2, S4.3, S4.4, U4.5 (SENSOR_VN/IO39)
Bat+: BAT+1.1, C19.2, L1.2, R6.1, R24.2
DAC_SOUND: R32.2, R33.2, U4.10 (DAC1/IO25)
ENC_A: C20.1, R34.1, U4.7 (IO35)
ENC_B: C32.2, R35.1, U4.6 (IO34)
ENC_OK: Encoder1.S1, R38.1, U4.9 (IO33)
ESP_EN: C29.1, Q2.3 (C), R28.2, R29.1, TFT1.2 (RST), U4.3 (EN)
GND: BAT-1.1, C1.1, C2.1, C3.2, C4.2, C5.1, C7.1, C8.1, C10.1, C11.1, C14.2, C16.2, C17.1, C18.1, C19.1, C20.2, C21.2, C22.2, C23.2, C24.2, C25.2, C26.2, C27.2, C28.2, C29.2, C30.2, C31.1, C32.1, Encoder1.C, Encoder1.MP, Encoder1.S2, J1.5 (GND), J1.S1 (SHIELD), J1.S2 (SHIELD), J1.S3 (SHIELD), J1.S4 (SHIELD), J1.S5 (SHIELD), J1.S6 (SHIELD), J2.1 (GND), J2.4 (GND), J3.6 (VSS), J3.9 (CARD_DETECTION), J3.10 (GND), J3.11, J3.12, J3.13, R7.2, R8.2, R13.2, R18.1, S2.1, S2.2, S4.1, S4.2, S6.P$4, S6.P$5, SW1.1, SW2.1 (A), SW3.1 (A), TFT1.1 (GND), TFT1.8 (GND), TFT1.11 (LED1-), TFT1.12 (LED2-), TFT1.13 (LED3-), TFT1.14 (LED4-), U1.1 (GND), U1.24 (/A9), U2.1 (GND), U2.24 (/A9), U3.1 (GND), U4.1 (GND), U4.15 (GND), U4.38 (GND), U4.39 (GND), U5.3 (GND_2), U5.9 (GND_3), U5.10 (GND_4), U5.13 (GND_5), U5.19 (GND), U5.21 (EP), U6.9 (GND), U7.1 (GND), U8.8 (GND), U8.13 (~OE), U9.8 (GND), U9.13 (~OE), Y3.2
HP_L: J2.2 (LEFT), U5.14 (HPLEFT)
HP_R: J2.3 (Right), U5.11 (HPRIGHT)
MIX_L: C9.2, C13.2
MIX_R: C12.2, C15.2
unnamed: C17.2, R23.2
unnamed: D1.2 (A), D2.1 (K), U6.2 (LED1)
unnamed: D1.1 (K), D2.2 (A), D3.1 (K), D4.2 (A), U6.4 (LED3)
unnamed: D3.2 (A), D4.1 (K), U6.3 (LED2)
unnamed: Encoder1.A, R34.2, R37.2
unnamed: Encoder1.B, R35.2, R36.1
unnamed: JP1.2 (B), TFT1.7 (SDO(MISO))
unnamed: Q1.1 (B), R1.1, R2.1
unnamed: Q2.1 (B), R26.2
unnamed: Q2.2 (E), R27.1, U3.14 (~RTS)
unnamed: Q3.1 (B), R27.2
unnamed: Q3.2 (E), R26.1, U3.13 (~DTR)
unnamed: R25.2, SW1.2
unnamed: R29.2, SW2.2 (B)
unnamed: R31.2, SW3.2 (B)
unnamed: C5.2, U3.4 (V3)
unnamed: U3.7 (XI), Y3.1
unnamed: U3.8 (XO), Y3.3
unnamed: R22.2, U4.34 (RXD0/IO3)
unnamed: R21.2, U4.35 (TXD0/IO1)
unnamed: C6.1, U5.17 (CPN)
unnamed: C6.2, U5.18 (CPP)
unnamed: C7.2, U5.15 (CPVSS_2), U5.16 (CPVSS)
unnamed: C14.1, U5.1 (LEFTINM)
unnamed: C13.1, U5.2 (LEFTINP)
unnamed: C11.2, U5.5 (RIGHTINM)
unnamed: C12.1, U5.4 (RIGHTINP)
unnamed: R24.1, U6.6 (BAT)
unnamed: R25.1, U6.5 (KEY)
unnamed: L1.1, U6.7 (SW)
unnamed: C21.1, C22.1, C23.1, S6.1, S6.2, U6.8 (Vout)
unnamed: U8.9 (QH'), U9.14 (SER)
RX0: R22.1, U3.2 (TXD)
SCL: R4.2, U4.36 (IO22), U5.8 (SCL)
SDA: R5.2, U4.33 (IO21), U5.7 (SDA)
SD_CS: J3.2 (CD/DAT3), U4.29 (IO5)
SPI_CLK: J3.5 (CLK), TFT1.3 (SCK), U4.30 (IO18)
SPI_MISO: J3.7 (DAT0), JP1.1 (A), U4.31 (IO19)
SPI_MOSI: J3.3 (CMD), TFT1.6 (SDA(MOSI)), U4.37 (IO23)
TFT_CS: TFT1.5 (CS), U4.16 (IO13)
TFT_DC: TFT1.4 (D/C), U4.14 (IO12)
TFT_LED: Q1.3 (C), TFT1.10 (LED+)
TFT_PWM: R1.2, U4.13 (IO14)
TX0: R21.1, U3.3 (RXD)
UD+: J1.3 (D+), U3.5 (UD+)
UD-: J1.2 (D-), U3.6 (UD-)
USB_SENS: R18.2, R19.1, U4.12 (IO27)
Vin: C18.2, J1.1 (VCC), R19.2, R23.1, U6.1 (Vin)
Vsens: R6.2, R7.1, U4.8 (IO32)

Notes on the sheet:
Не запаивать

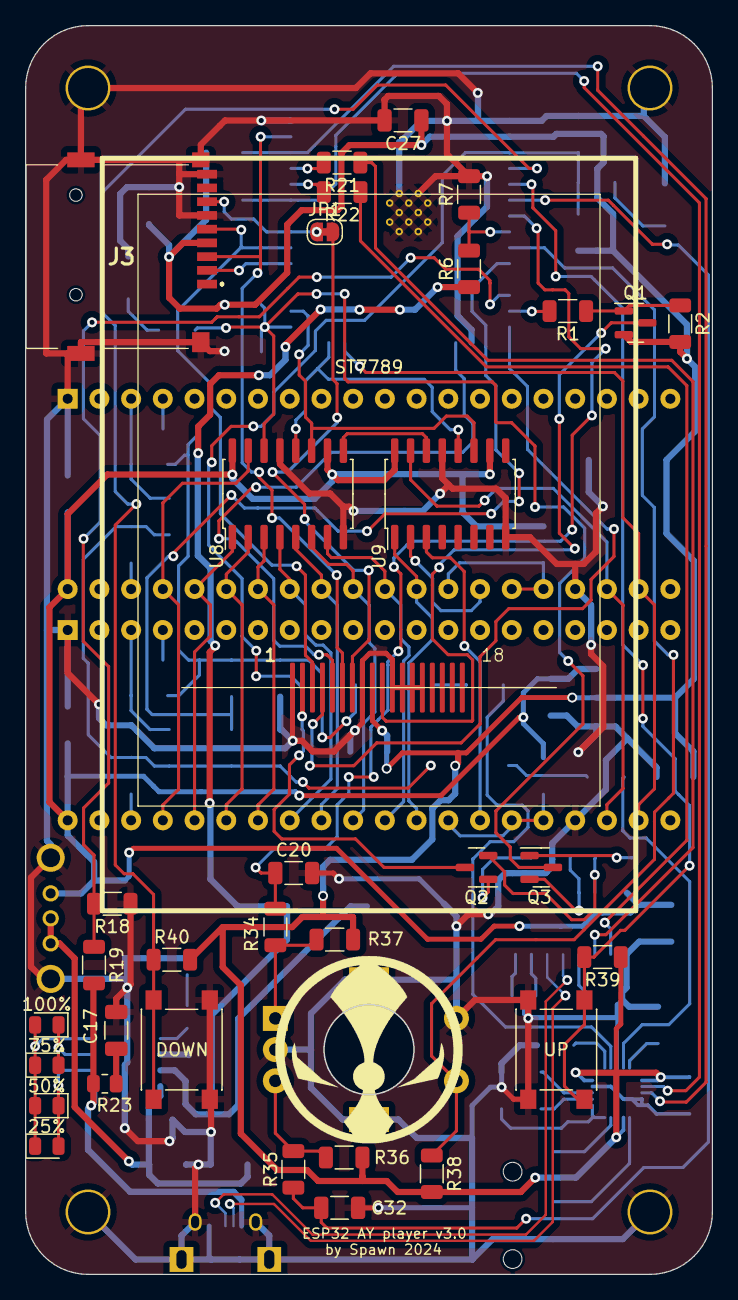
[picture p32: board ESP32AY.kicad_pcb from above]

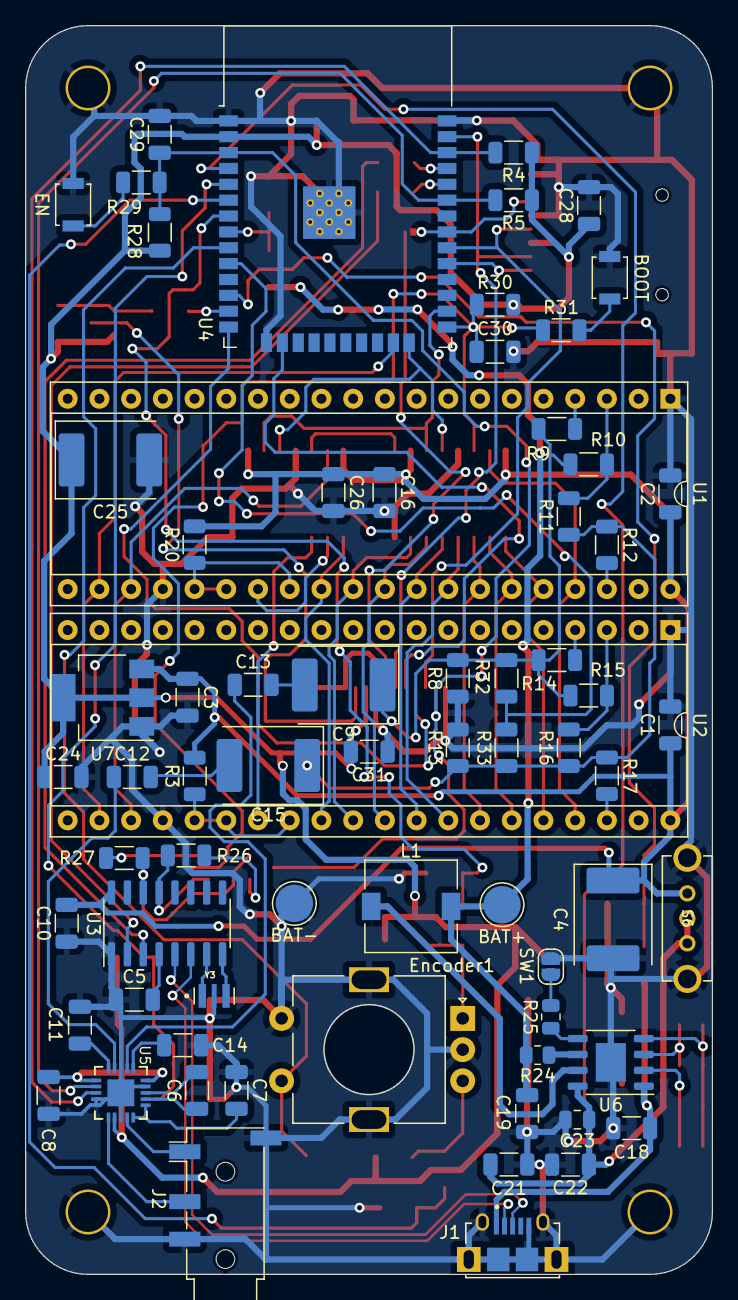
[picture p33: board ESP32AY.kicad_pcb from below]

Board: 2 copper layers, 55.0 x 100.0 mm, 104 parts (69 on the bottom side), 90 nets.

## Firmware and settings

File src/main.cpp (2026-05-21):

#include <Arduino.h>
#if defined(CONFIG_IDF_TARGET_ESP32S3) && defined(BOARD_HAS_PSRAM)
  #include "s3wrapper.h"
#endif
#include <SPI.h>
#include <SdFat.h>
#include "esp_task_wdt.h"
#include "freertos/FreeRTOS.h"
#include "freertos/semphr.h"

#ifdef DEBUG_RAM
#include "debug.h"
#endif

#include "defines.h"
#include "rtc.h"
#include "amp.h"
#include "keypad.h"
#include "tftui.h"
#undef FILE_READ
#undef FILE_WRITE
#include "config.h"
#include "playlist.h"
#include "browser.h"

#include "sound.h"
#include "eq.h"
#include "ay.h"
#include "ayflyw.h"

#include "players/ASCPlay.h"
#include "players/PSCPlay.h"
#include "players/PT1Play.h"
#include "players/PT2Play.h"
#include "players/PT3Play.h"
#include "players/SQTPlay.h"
#include "players/STCPlay.h"
#include "players/STPPlay.h"
#include "players/AYPlay.h"
#include "players/PSGPlay.h"
#include "players/MODPlay.h"
#include "players/S3MPlay.h"
#if defined(CONFIG_IDF_TARGET_ESP32S3)
#include "players/XMPlay.h" 
#endif
#include "players/TAPPlay.h"
#include "players/TZXPlay.h"
#include "players/MP3Play.h"
#include "players/WAVPlay.h"

// #include "sdTest.h"
#include "player.h"
#include "uart.h"

void setup(){
#ifdef DEBUG_RAM
  printf("Setup start\n");
  checkHeap();
#endif
  initSemaphore();
  i2cInit();
  blPinSetup();
  display_brightness(0);
  startup_config_load();
  ampInit();
  muteAmp();
  checkStartUpConfig();
  initRTC();
  setRTC();
  printRTCStatus();
  initVoltage();
  TFTInit();
  buttonsSetup();
  DACInit();
  AYInit();
  introTFT();
  delay(2000);
  show_frame();
  playerSourceChange(); // ay playcore or uart playcore
  checkSDonStart();
  muteAYBeep();
  if(lfsConfig.playerSource==PLAYER_MODE_UART) unMuteAmp();
#ifdef DEBUG_RAM
  printf("Setup end\n");
  checkHeap();
#endif  
}

void loop(){
  getDateTime();
  generalTick();
  player();
  switch(PlayerCTRL.screen_mode){
    case SCR_PLAYER:
      player_screen();
      break;
    case SCR_BROWSER:
      browser_screen(sdConfig.isBrowserPlaylist);
      break;
    case SCR_CONFIG:
      config_screen();
      break;
    case SCR_RESET_CONFIG:
      config_reset_default_screen();
      break;
    case SCR_DATETIME:
      time_date_screen();
      break;
    case SCR_ABOUT:
      config_about_screen();
      break;
    case SCR_NOFILES:
      noFilesFound();
      checkSDonStart();
      break;
    case SCR_SDEJECT:
      sdEject();
      checkSDonStart();
      break;
    case SCR_ALERT:
      alert_screen();
      break;
  }
  // Yield to other tasks more frequently for better encoder response
  taskYIELD();
  vTaskDelay(pdMS_TO_TICKS(1));
  scrTimeout();
  esp_task_wdt_reset();
}

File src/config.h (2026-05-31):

#include <LittleFS.h>
#include "csmos.h"
#if defined(CONFIG_IDF_TARGET_ESP32S3)&&(ARDUINO_USB_MODE==0)&&(ARDUINO_USB_CDC_ON_BOOT==1)
#include "Adafruit_TinyUSB.h"
Adafruit_USBD_MSC usb_msc;
bool sdMounted=false;
bool usbTaskRunning=false;
bool osEjected=false;
bool msc_changed=false;
bool usbConnected=false;
TaskHandle_t usbTaskHandle=NULL;
bool msc_read_active=false;
bool msc_write_active=false;
uint32_t msc_read_time=0;
uint32_t msc_write_time=0;
#endif

bool cfgSet=false;
bool sdFlag=false;
bool cfgDateTimeSet=false;

// Forward declarations
void sd_config_save();
void lfs_config_save();
void setTapSpeed();
void setTzxSpeed();

//ESP32S3 usb <--> SD mass storage device
#if defined(CONFIG_IDF_TARGET_ESP32S3)&&(ARDUINO_USB_MODE==0)&&(ARDUINO_USB_CDC_ON_BOOT==1)
void mountSD(){
  if(osEjected) return;
  if(sd_fat.card()){
    if(!sdMounted){
      uint32_t block_count=sd_fat.card()->sectorCount();
      usb_msc.setCapacity(0,block_count,512);
      sdMounted=true;
    }
    usb_msc.setUnitReady(0,true);
  }else if(sd_fat.begin(SD_CONFIG)){
    uint32_t block_count=sd_fat.card()->sectorCount();
    usb_msc.setCapacity(0,block_count,512);
    usb_msc.setUnitReady(0,true);
    sdMounted=true;
  }
}

void umountSD(){
  osEjected=true;
  usb_msc.setUnitReady(0,false);
  sdMounted=false;
}

void usbMscTask(void* parameter){
  while(1){
    if(TinyUSBDevice.isInitialized()){
      TinyUSBDevice.task();
    }
    vTaskDelay(pdMS_TO_TICKS(50));
  }
}

void tud_mount_cb(void){
  usbConnected=true;
  if(osEjected){
    osEjected=false;
  }
  mountSD();
}

void tud_umount_cb(void){
  usbConnected=false;
  sdMounted=false;
}

void tud_suspend_cb(bool remote_wakeup_en){
  (void)remote_wakeup_en;
  usbConnected=false;
  sdMounted=false;
}

bool msc_start_stop_cb(uint8_t power_condition,bool start,bool load_eject){
  if(load_eject&&!start){
    osEjected=true;
    sdMounted=false;
  }
  return true;
}

bool msc_writable_cb(){
  return !osEjected;
}

int32_t msc_read_cb(uint32_t lba,void* buffer,uint32_t bufsize){
  bool rc;
  msc_read_active=true;
  msc_read_time=millis();
  if(xSemaphoreTake(sdCardSemaphore,portMAX_DELAY)==pdTRUE){
    rc=sd_fat.card()->readSectors(lba,(uint8_t*)buffer,bufsize/512);
    xSemaphoreGive(sdCardSemaphore);
  }
  return rc?bufsize:-1;
}

int32_t msc_write_cb(uint32_t lba,uint8_t* buffer,uint32_t bufsize){
  bool rc;
  msc_write_active=true;
  msc_write_time=millis();
  if(xSemaphoreTake(sdCardSemaphore,portMAX_DELAY)==pdTRUE){
    rc=sd_fat.card()->writeSectors(lba,buffer,bufsize/512);
    if(rc) msc_changed=true;
    xSemaphoreGive(sdCardSemaphore);
  }
  return rc?bufsize:-1;
}

void msc_flush_cb(void){
  if(xSemaphoreTake(sdCardSemaphore,portMAX_DELAY)==pdTRUE){
    if(msc_changed){
      sd_fat.card()->syncDevice();
      sd_fat.cacheClear();
      msc_changed=false;
    }
    xSemaphoreGive(sdCardSemaphore);
  }
}

bool msc_ready_cb(){
  return !osEjected;
}

void s3Serial(){
  TinyUSBDevice.setProductDescriptor("ZxPOD AY/YM Serial");
  TinyUSBDevice.setManufacturerDescriptor("Spawn Development");
  if(TinyUSBDevice.mounted()){
    TinyUSBDevice.detach();
    delay(10);
    TinyUSBDevice.attach();
  }
}

void massStorage(){
  TinyUSBDevice.setProductDescriptor("ZxPOD Mass Storage Device");
  TinyUSBDevice.setManufacturerDescriptor("Spawn Development");
  usb_msc.setID("ZxPOD","SD",FULL_VERSION);
  usb_msc.setReadWriteCallback(0,msc_read_cb,msc_write_cb,msc_flush_cb);
  usb_msc.setStartStopCallback(0,msc_start_stop_cb);
  usb_msc.setReadyCallback(0,msc_ready_cb);
  usb_msc.setWritableCallback(0,msc_writable_cb);
  mountSD();
  usb_msc.begin();
  if(!usbTaskRunning){
    usbTaskRunning=true;
    xTaskCreatePinnedToCore(usbMscTask,"USB MSC",4096,NULL,1,&usbTaskHandle,0);
  }
  if(TinyUSBDevice.mounted()){
    TinyUSBDevice.detach();
    delay(10);
    TinyUSBDevice.attach();
  }
 }

// USB Bootloader Reset - simplified version usb_switch_to_cdc_jtag()
static void usb_switch_to_cdc_jtag_copy(){
  // switch to hardware CDC+JTAG
  CLEAR_PERI_REG_MASK(RTC_CNTL_USB_CONF_REG,(RTC_CNTL_SW_HW_USB_PHY_SEL|RTC_CNTL_SW_USB_PHY_SEL|RTC_CNTL_USB_PAD_ENABLE));
  // don't use external PHY
  CLEAR_PERI_REG_MASK(USB_SERIAL_JTAG_CONF0_REG,USB_SERIAL_JTAG_PHY_SEL);
  // disable GPIO from CDC+JTAG
  CLEAR_PERI_REG_MASK(USB_SERIAL_JTAG_CONF0_REG,USB_SERIAL_JTAG_USB_PAD_ENABLE);
  // Force the host to re-enumerate (BUS_RESET)
  pinMode(USBPHY_DM_NUM,OUTPUT_OPEN_DRAIN);
  pinMode(USBPHY_DP_NUM,OUTPUT_OPEN_DRAIN);
  digitalWrite(USBPHY_DM_NUM,LOW);
  digitalWrite(USBPHY_DP_NUM,LOW);
  delay(50);
  // Connecting GPIO to the integrated CDC+JTAG
  SET_PERI_REG_MASK(USB_SERIAL_JTAG_CONF0_REG,USB_SERIAL_JTAG_USB_PAD_ENABLE);
  delay(100);
}
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

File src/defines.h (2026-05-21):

#include <AudioFileSourceSDFAT.h>
#include <SPI.h>
#include <Wire.h>

#define FW_VERSION         "3.7"
#include "build_info.h"
#define LFSCONFIG_VERSION 2  // Increment when lfsConfig structure changes
#define SDCONFIG_VERSION  2  // Increment when sdConfig structure changes

#define CLK_SPECTRUM  	1773400
#define CLK_PENTAGON  	1750000
#define CLK_MSX			    1789772
#define CLK_CPC			    1000000
#define CLK_ATARIST		  2000000

#define FPS_PENTAGON  	48828
#define FPS_SPECTRUM  	50000
#define FPS_NTSC	  	  60000

#define CFG_FILENAME  "/config.cfg"

#define TIMER_RATE  44100

#ifdef USE_EXTERNAL_DAC
#define PIN_BCK 25
#define PIN_DIN 26
#define PIN_LCK 27
#endif

#if defined(CONFIG_IDF_TARGET_ESP32S3)
#define PIN_BCK 4
#define PIN_DIN 5
#define PIN_LCK 6
#endif

// SD configs
#if defined(CONFIG_IDF_TARGET_ESP32S3)
#define SD_CS    10
#define SD_MOSI  11
#define SD_SCK   12
#define SD_MISO  13
#define SD_CONFIG SdSpiConfig(SD_CS,DEDICATED_SPI,SD_SCK_MHZ(50)) // 39 max
#else
#define SD_CONFIG SdSpiConfig(SS,DEDICATED_SPI,SD_SCK_MHZ(30)) // 39 max
#endif

#define MAX_PATH  260

// Declare the semaphore handle
SemaphoreHandle_t sdCardSemaphore=NULL;
SemaphoreHandle_t outSemaphore=NULL;

//--------------------------------------
// count of voltage read - REDUCED for performance
#define READ_CNT 20  // Was 100, now 20 for faster ADC reads
#if defined(CONFIG_IDF_TARGET_ESP32S3)
// voltmeter pin
#define VOLTPIN 7
#else
// voltmeter pin
#define VOLTPIN 32
#endif

#if defined(CONFIG_IDF_TARGET_ESP32)
#ifndef USE_EXTERNAL_DAC
//charge sense
#define CHGSENS 27
#endif
#endif

#if defined(CONFIG_IDF_TARGET_ESP32S3)
//charge sense
#define CHGSENS 38
#endif
// internal Vref (need to set)
const float VRef=1.1;
// Input resistive divider ratio (Rh + Rl) / Rl. IN <-[ Rh ]--(analogInPin)--[ Rl ]--|GND
const float VoltMult=(100.0+10.0)/10.0;
// maximum battery charge voltage (need to set)
const float v_max=4.1;
// minimum battery charge voltage (need to set)
const float v_min=3.0;
// voltage
float volt=0;
// charge precent
uint8_t precent=0;
// index of battery sprite
uint8_t spriteIndex=0;
// voltmeter update each ms - INCREASED for less frequent updates
#define V_UPD 5000  // Was 2000ms, now 5000ms (5 seconds)
unsigned long mlsV=0;
unsigned int vUp=V_UPD;
bool batChange=true;
//--------------------------------------
bool keysEvent=false;
bool lcdBlackout=false;
bool scrNotPlayer=false;
bool tftInitialized=false;
unsigned long mlsScr=0;
unsigned long mlsPrevTrack=0;
unsigned long loadingTime=0;
#define PREVTRACKDELAY 2000

#define S_UPD0 6  // browser cur filename
#define S_UPD1 10 // player name
#define S_UPD2 15 // player author
#define S_UPD3 6  // player file
#define S_UPD4 20 // date
#define S_UPD5 20 // browser header
// scroll end or start
#define S_UPD_DIR 1000
unsigned int sUpC[6]={S_UPD0,S_UPD1,S_UPD2,S_UPD3,S_UPD4,S_UPD5};
unsigned int sUp[6]={S_UPD0,S_UPD1,S_UPD2,S_UPD3,S_UPD4,S_UPD5};

unsigned long mls=0;
unsigned long mlsS[6]={0,0,0,0,0,0};
int sPos[6]={0,0,0,0,0,0};
bool scrollDir[6]={true,true,true,true,true,true};

// bool update_list=true;
bool scroll=false;
uint16_t scrollSY=0;

uint8_t modEQchn[8];
uint8_t modChannels=0;
uint8_t modChannelsEQ=0;
int bitrate=0;
int channelMode=0;
bool isVBR=false;

SdFs sd_fat;
FsFile sd_dir;
FsFile sd_file;
FsFile sd_play_dir;
FsFile sd_play_file;
AudioFileSourceSDFAT *modFile=NULL;
bool skipMod=false;
volatile bool xmCleanupInProgress=false;  // Флаг для синхронизации при удалении XM

uint8_t music_data[48*1024];
uint32_t music_data_size;

char lfn[MAX_PATH]; //common array for all lfn operations
char playFileName[MAX_PATH];
char scrollbuf[MAX_PATH*2]; // doubled for header scroll (first half for files, second for header)
char playedFileName[MAX_PATH];
byte fileInfoBuf[128]; // 31 bytes per frame max, 50*31=1550 per sec, 155 per 0.1 sec
char tme[200];

extern bool &ayPlayerAct;

volatile uint32_t frame_cnt=0;
volatile uint32_t frame_div=0;
volatile uint32_t frame_max=TIMER_RATE*1000/48880; // Pentagon int

struct{
  uint8_t version;              // Config version for validation
  uint8_t browser_sort;         // Browser sort mode
  bool isBrowserPlaylist;       // browser mode
  bool isPlayAYL;               // player mode
  int16_t dir_cur;              // Browser cursor pointer
  int16_t play_cur;             // Player pointer
  int16_t dir_cur_prev;         // Previous browser pointer
  int16_t play_prev_cur;        // Previous player pointer
  uint8_t volume;               // Amp current volume 32 (0...63)
  uint16_t play_count_files;    // Player count files in dir
  uint16_t play_cur_start;      // Start from pointer
  char play_dir[MAX_PATH];      // Play dir path
  char active_dir[MAX_PATH];    // Browser active dir path
  char prev_dir[MAX_PATH];      // Previous dir path
  char ayl_file[MAX_PATH];      // Browser ayl file path
  char play_ayl_file[MAX_PATH]; // Current playing playlist file path
}sdConfig;
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

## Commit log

2024-06-26 add PCB project and Gerbers
    [2.4 TFT Module.step, 35RAPC2BHN2.step, AYDIP40_MODEL.STEP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]
2024-06-26 add Case stl models
    [ESP32AYBottom.stl, ESP32AYTop.stl]
2024-10-22 add: new feature - Playing over UART
2024-10-22 fix: settings menu bug
    [config.h]
2024-11-13 PCB Rev. B (Type-C and Stereo DAC)
    [ESP32AY.kicad_pcb, ESP32AY.kicad_sch, ESP32AYBottom.stl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]
2024-11-20 fix backlight screen noise
    [main.cpp, tftui.h]
2024-11-20 Dual Channel DAC for PCB rev.B
2025-02-09 fix issues #5 and #6, add search supported files on whole SD card includes subfolders.
    [browser.h, defines.h, main.cpp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]
2025-02-09 fix: highlight the playback folder in the file browser along the entire path.
    [browser.h]
2025-02-09 fix: highlight whole playing path path folders and playlists
    [browser.h]
2025-02-16 fix: some errors with spi class and backlight setup
    [defines.h, tftui.h]
2025-03-04 Release 3.4 (added mod+s3m formats), LCD moved to dedicated SPI with revision C PCB or soldering upgrade from revision A and B to revision C (see README). Some optimizations and new features.
    [2.4 TFT Module.step, 35RAPC2BHN2.step, AYDIP40_MODEL.STEP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]
2025-04-09 Refactored schematics, updated BOM
    [ESP32AY.kicad_pcb, ESP32AY.kicad_sch]
2025-04-09 Updated page settings (revision number, etc)
    [ESP32AY.kicad_pcb, ESP32AY.kicad_sch]
2025-04-10 Added C30 to the charger unit
    [ESP32AY.kicad_pcb, ESP32AY.kicad_sch]
2025-04-10 Fixed R7 from 20k to 10k
    [ESP32AY.kicad_pcb, ESP32AY.kicad_sch]
2025-04-11 Fix extit from config menu (volume triggered on exit), fix silence on pause and change track, some changes on "about" screen:)
    [config.h, defines.h, main.cpp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]
2025-04-14 Add root config for change encoder type (see README) and reset config before start up.
    [config.h, defines.h, main.cpp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]
2025-04-14 add release button notification on enter root menu
2025-04-14 Schematics change: replaced R19 from 0 to 8K2
    [ESP32AY.kicad_pcb, ESP32AY.kicad_sch]
2025-05-21 add encoder direction setting in config menu
2025-05-23 fix encoder direction start initialization
2025-06-15 fix: battery calibration actions in menu
    [config.h]
2025-06-16 Add RTC and EEPROM features, prepare to rev. D PCB (ESP32S3)
2025-06-16 fix short day of week on main screen instead of long
    [player.h]
2025-06-16 fix bin file for ESP32S3
2025-06-18 organizing all PCB revisions into their own folders
    [2.4 TFT Module.step, 35RAPC2BHN2.step, AYDIP40_MODEL.STEP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]
2025-06-19 add mod samples in PSRAM on S3. fix some actions in channelEQ in mods.
    [MODPlay.h, defines.h]
2025-06-21 fix s3m 16-bit samples and skip OPL samples.
    [S3MPlay.h]
2025-06-21 add s3m PSRAM support for ESP32-S3 with PSRAM. Some s3m fixes.
    [S3MPlay.h]
2025-06-21 fix some spaces in code.
    [MODPlay.h, S3MPlay.h]
2025-06-21 init xm implementation
    [custom_partitions.csv]
2025-07-14 fix amp and rtc addresses
    [defines.h]
2025-07-16 added SD forwarding via USB as Mass Storage device (rev.D only)
2025-07-16 fix encoder default direction for rev.D
2025-07-16 fix slow RTC setup
    [config.h]
2025-07-30 Some PCB and code fixes
    [ESP32AY-revD.kicad_pcb, ESP32AY-revD.kicad_sch]
2025-09-18 fix xm playing time calculation. add reset last playing track. minor fixes.
    [config.h, defines.h, player.h]
2025-10-09 fix ay format rendering and playing
    [player.h]
2025-10-09 fix ay BCA layer
    [ay.h]
2025-10-10 fix some issues when switching from the .ay format, add DAC Gain in config.
    [MODPlay.h, S3MPlay.h, XMPlay.h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]
2025-10-15 fix pause on change tapes formats
    [player.h]
2025-10-15 fix pause on change tapes formats and mass storage mount for rev.D
    [config.h, player.h]
2025-10-15 fix time recalculating on change tapes turbo modes
    [config.h]
2025-10-17 fix TAPE formats with block change and turbo load modes + minor fixes.
    [player.h]
2025-10-20 fix .mod patternloop effect, also check sample boundaries before processing the loop.
2025-11-07 add new cases
    [BottomMicroUsbRevA.stl, BottomRevABCD.stl, BottomTypeCRevBC.stl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]
2025-11-09 some minor fixes + fix skip mp3 cover art in player.
    [config.h, csmos.h, defines.h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]
2025-11-10 Many optimizations for RAM and screen rendering have been made, and file sorting has been added to the browser. some minor fixes.
    [browser.h, config.h, defines.h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]
2025-11-10 fix change ay clock on mp3/wav formats.
    [player.h]
2026-05-15 fix reset RTC, some minor fixes
    [config.h, main.cpp, tftui.h]
2026-05-15 fix DAC formats volumes
    [ay.h]
2026-05-15 fix XM freezes, responsiveness of the encoder and buttons
    [XMPlay.h, defines.h, main.cpp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]
2026-05-15 implementation of the assembly number and date into the project
2026-05-16 fix player freeze on xm track change
    [XMPlay.h, defines.h]
2026-05-16 switching from debug to production mode
2026-05-16 fix XM file validations and playback time
    [XMPlay.h]
2026-05-17 fix mod current time sync
2026-05-17 Fix MOD player: uint32_t for sample length and bounds checks
2026-05-21 change platform to 7.0.1, add scrollbar in browser, add fast turn encoder in browser
2026-05-28 refactor SD-USB mount in CtartupConfig menu! (press left button and turn on player)
2026-05-30 fix SD<--->USB detect and mount
    [config.h]
2026-06-07 add revD2 where fix Audio mixer
    [2.4 TFT Module.step, 35RAPC2BHN2.step, ARDUINO_NANO.step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]
2026-06-07 fix ay track change silence from playlists
    [browser.h]
2026-07-12 fix xm channels up to 46
    [XMPlay.h]
